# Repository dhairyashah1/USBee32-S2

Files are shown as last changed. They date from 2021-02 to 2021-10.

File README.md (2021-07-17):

# USBee32-S2 : ESP32-S2 Hardware Design

<p align="center">





  </br>
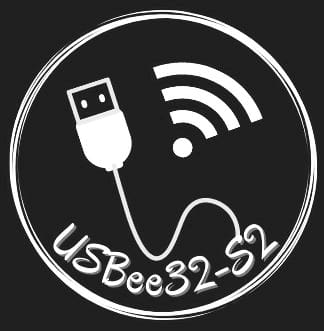
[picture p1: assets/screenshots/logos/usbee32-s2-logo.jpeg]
</p>
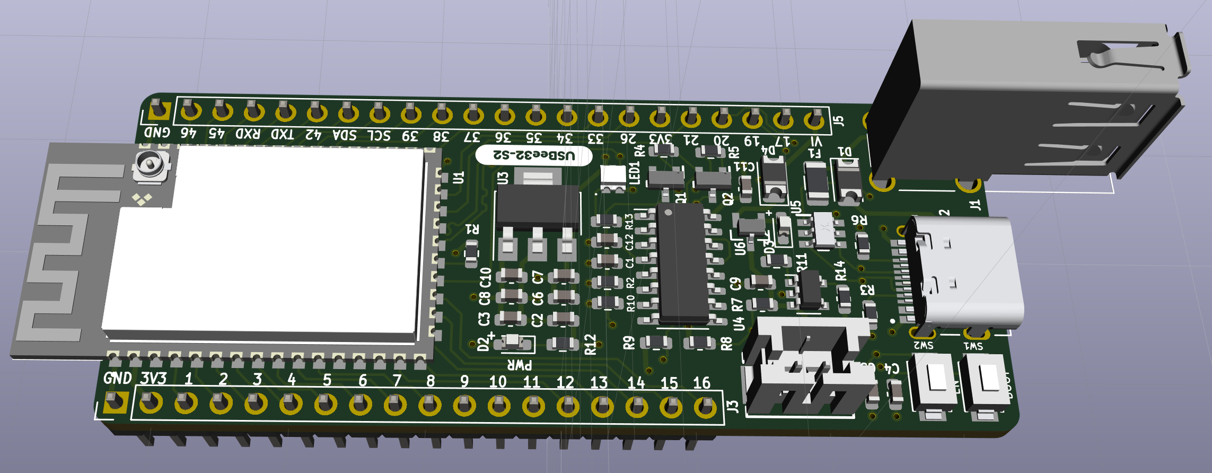
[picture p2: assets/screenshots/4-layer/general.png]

</br>
This repository contains hardware design files and datasheets for the ESP32-S2. This is an open source ESP32-S2 based PCB with breakout ports for both USB - Type A and USB - Type C.
</br>

## Features

* Small form factor of 68.4mm x 27.9mm
* Four layered customly designed general purpose Development board
* Uses ESP32-S2-WROOM RF module
* Breakout ports for both USB - Type A and USB - Type C
* Uses CH340C which gives a high current output converting USB to UART logic
* Powering modes for the ESP - Either can be used
  - USB - A: Using a USB A Male Cable
  - USB - C: Using a USB C Male Cable(Typical Mobile charger cable)
  - VI Pin: Supplying this GPIO pin with external 5V
* Has a On - board debuggable Neopixel (RGB Led)
* Has an ESD protection device which protects the circuit from electrostatic discharge and prevents malfunction/breakdown of the device
* Uses MCP73831 for charging LiPo battery
* Can use it as a power/communicating device for a joystick/ game controller
* Space efficient PCB with integrating majority components in SMD type package 

## Project Structure

```
/assets/datasheets  - contains datasheets of various components used in the PCB
/assets/references  - contains references for the PCB
/assets/schematics  - contains schematics of the the PCB
/assets/screenshots - contains screenshots of the the PCB
.
├── assets
│   ├── datasheets   - contains datasheets of various components used in the PCB         
│   ├── references   - contains references used in making the PCB
│   ├── schematics   - contains schematics of the PCB
│   └── screenshots  - contains screenshots of the PCB
├── gerbers          - contains exportable gerber files of the PCB
├── renders          - contains models and renders of the PCB
└── USBee32-S2       
    ├── component_libraries  - contains external component libraries used 
    └── ...                  - various KiCAD PCB files
```

## Tools

To view/modify the files from this repository, install KiCAD from: [https://kicad.org](https://kicad.org)

## Schematics

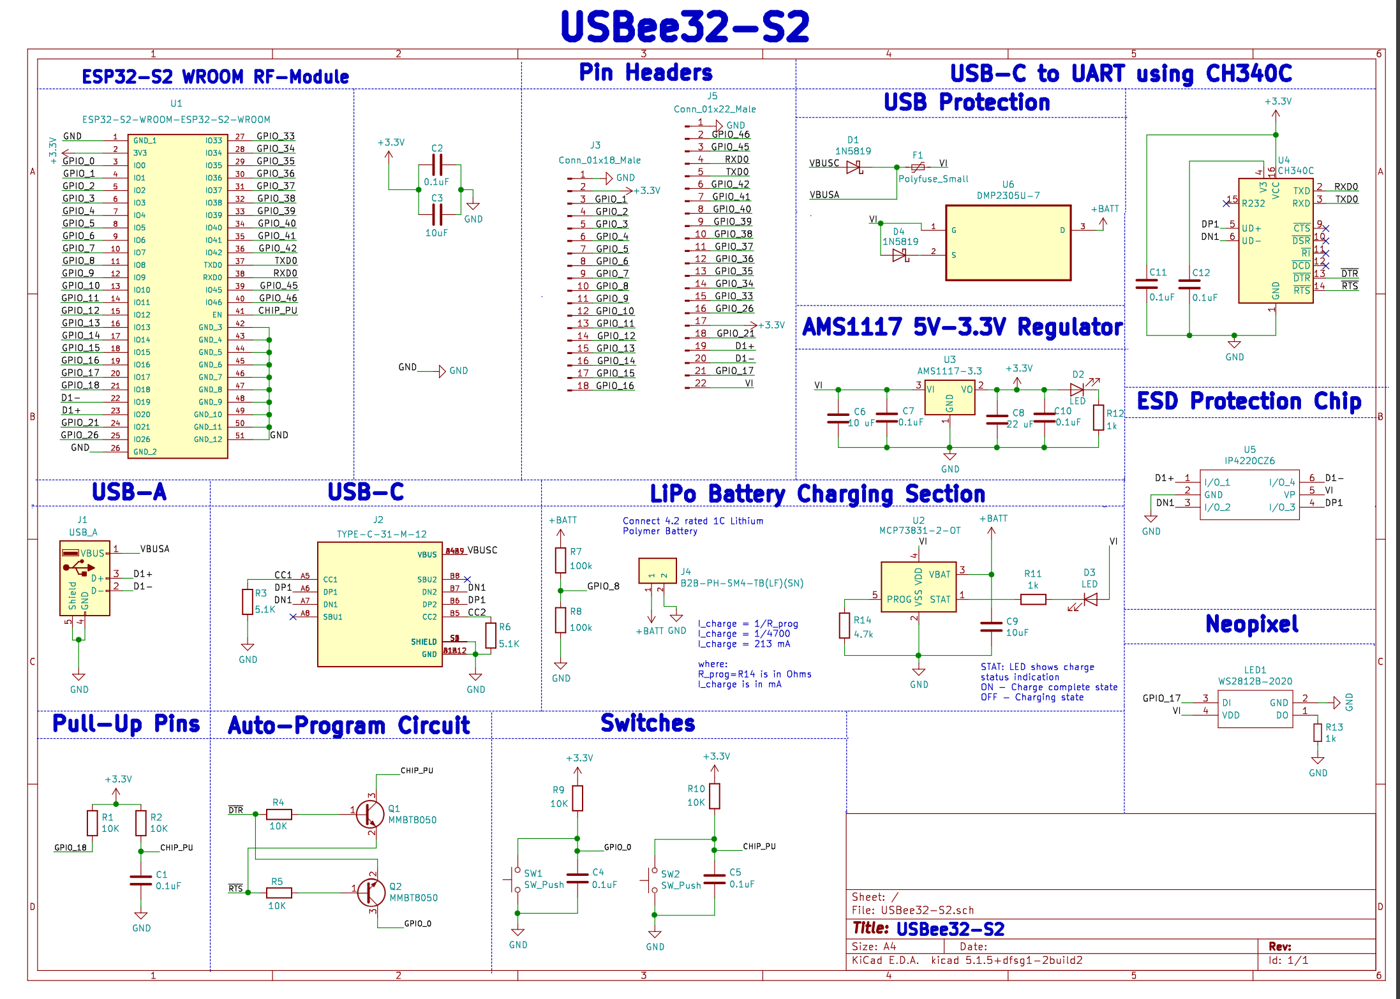
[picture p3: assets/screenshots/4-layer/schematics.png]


## Plots
### Front side

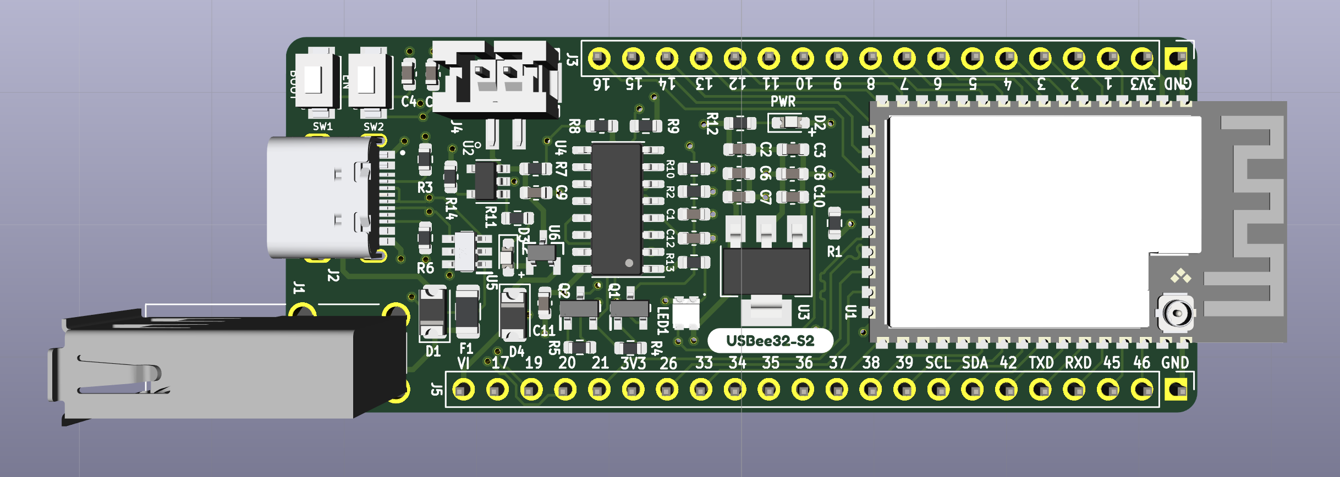
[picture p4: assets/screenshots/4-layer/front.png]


### Back side

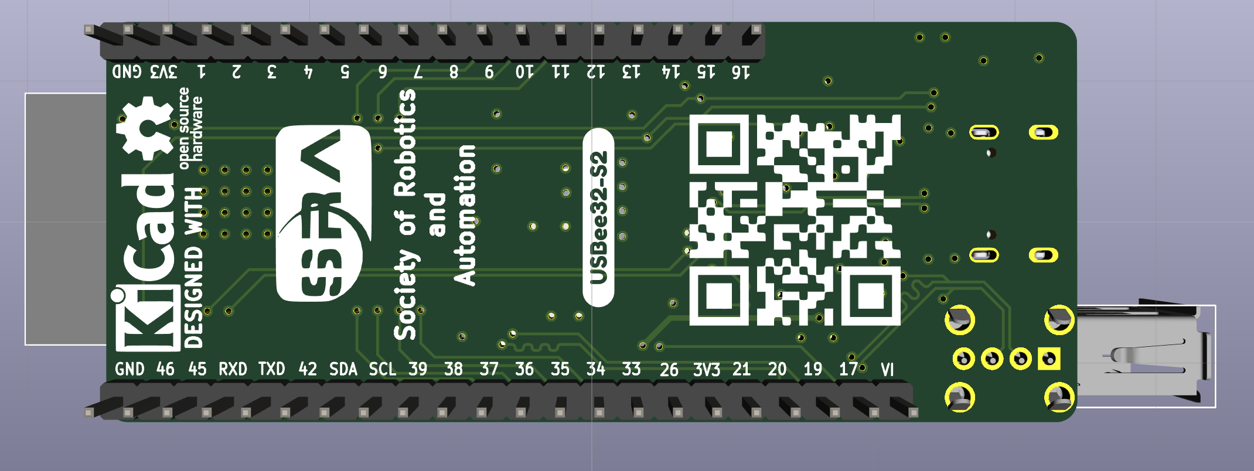
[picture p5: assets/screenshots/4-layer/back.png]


## Future work

- [x] Switching to a 4-layer PCB to make it more space efficient
- [x] Adding safety against electrostatic discharge (ESD)
- [x] Adding Neopixel RBG Leds
- [x] Adding Battery charging circuit
- [x] Adding Safety against ESD - Electrostatic Discharge
- [ ] Adding extra components to the board to deliver better functionality (Eg: OLED)
- [ ] Adding various general purpose sensors 
- [ ] Adding Firmware support

## Documentation
- Click [here](https://dhairyashah1.github.io/USBee32-S2/) to view

## Bill of Materials
- Click [here](https://docs.google.com/spreadsheets/d/1pFtIJ-MqmLt7VhAe4oJemrvx9vsikKc4zFzRtyDyzKU/) to view

<!-- CONTRIBUTORS -->
## Contributors

- [Dhairya Shah](https://github.com/dhairyashah1): *Designer*
- [Chaitravi Chalke](https://github.com/chaitravi-ce): *Designer*
- [Sakshi Chikshe](https://github.com/Sakshi-0311): *Designer*
- [Vedant Paranjape](https://github.com/VedantParanjape): *Mentor*
- [Omkar Bhilare](https://github.com/ombhilare999): *Mentor*

## Sponsorship
- Thanks to PCBWay for sponsoring the first Prototypes.
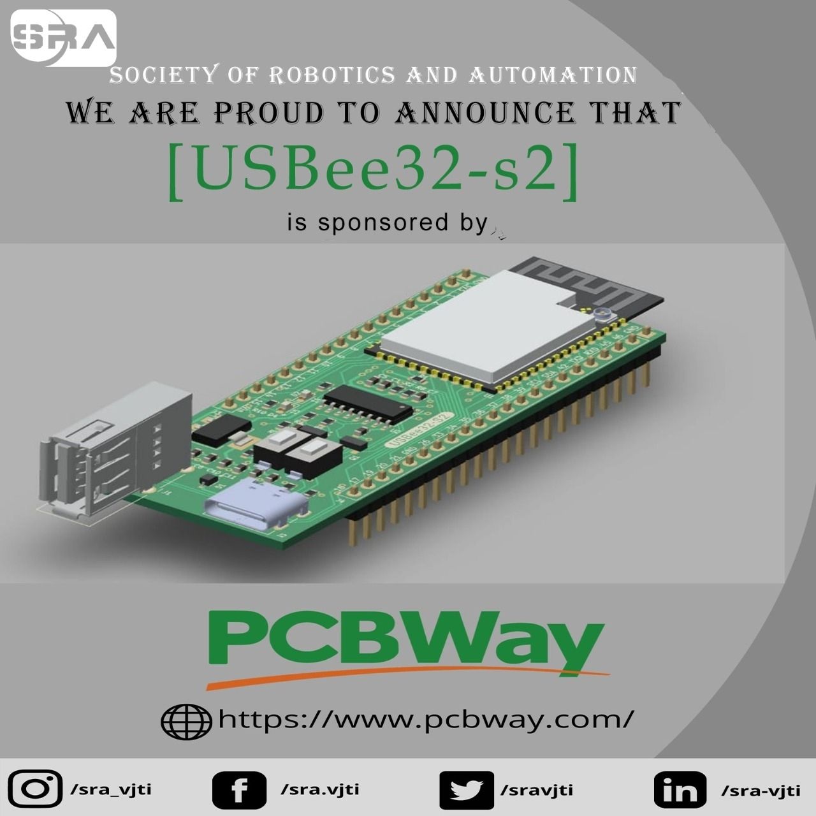
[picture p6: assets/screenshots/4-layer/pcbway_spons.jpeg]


## Organization
- [SRA-VJTI](https://github.com/SRA-VJTI)

## License
- Distributed under the [MIT License](https://github.com/dhairyashah1/pcb-design-ESP32-S2/blob/main/LICENSE).

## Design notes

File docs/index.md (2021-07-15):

# Overview

<p align="center">
    <a href="https://github.com/dhairyashah1/USBee32-S2/tree/4-layerr">
        
    </a>
</p>

<p align="center">





</p>

The USBee32-S2 is an Open Source, General Purpose, USB (Type A and Type C) Breakout Development Board designed using ESP32-S2-WROOM Module. 

The features of USBee32-S2 [printed circuit board](https://github.com/dhairyashah1/USBee32-S2/tree/4-layer) are:   

* Small form factor of 68.4mm x 27.9mm
* Four layered customly designed general purpose Development board
* Uses ESP32-S2-WROOM RF module
* Breakout ports for both USB - Type A and USB - Type C
* Uses CH340C which gives a high current output converting USB to UART logic
* Powering modes for the ESP - Either can be used
  - USB - A: Using a USB A Male Cable
  - USB - C: Using a USB C Male Cable(Typical Mobile charger cable)
  - VI Pin: Supplying this GPIO pin with external 5V
  - JST Battery Port
* Has an On - board debuggable Neopixel (RGB Led)
* Has an ESD protection device which protects the circuit from electrostatic discharge and prevents malfunction/breakdown of the device
* Uses MCP73831 for charging LiPo battery
* Can use it as a power/communicating device for a joystick/ game controller
* Space efficient PCB with integrating majority components in SMD type package 
* Autoselect power source, i.e., battery or USB

## Gallery
<!-- 
## Project logs

* Hackaday: [https://hackaday.io/project/176959-open-authenticator](https://hackaday.io/project/176959-open-authenticator)
## Join the Discussion: -->

<!-- * Discord: [https://discord.gg/kVDdB9kAEP](https://discord.gg/kVDdB9kAEP) -->
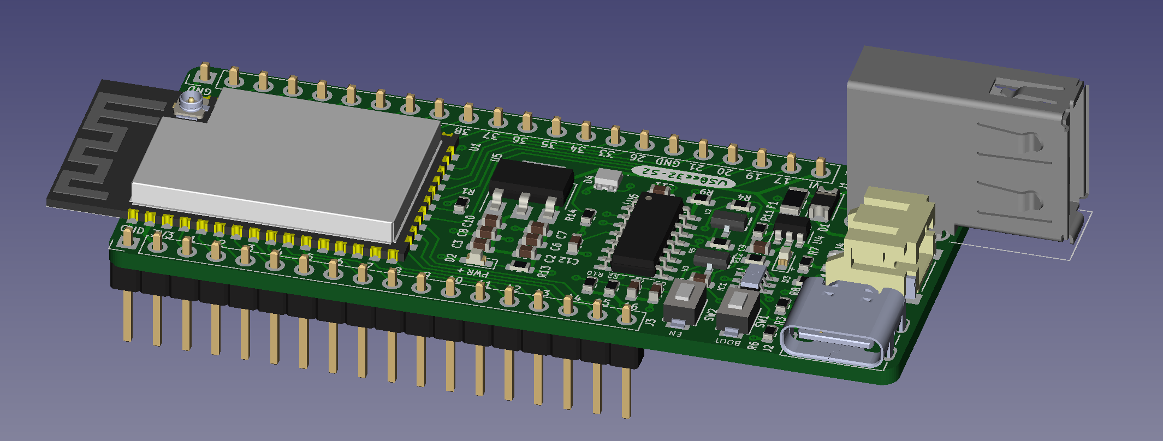
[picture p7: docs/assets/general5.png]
- <h3>General view</h3> 
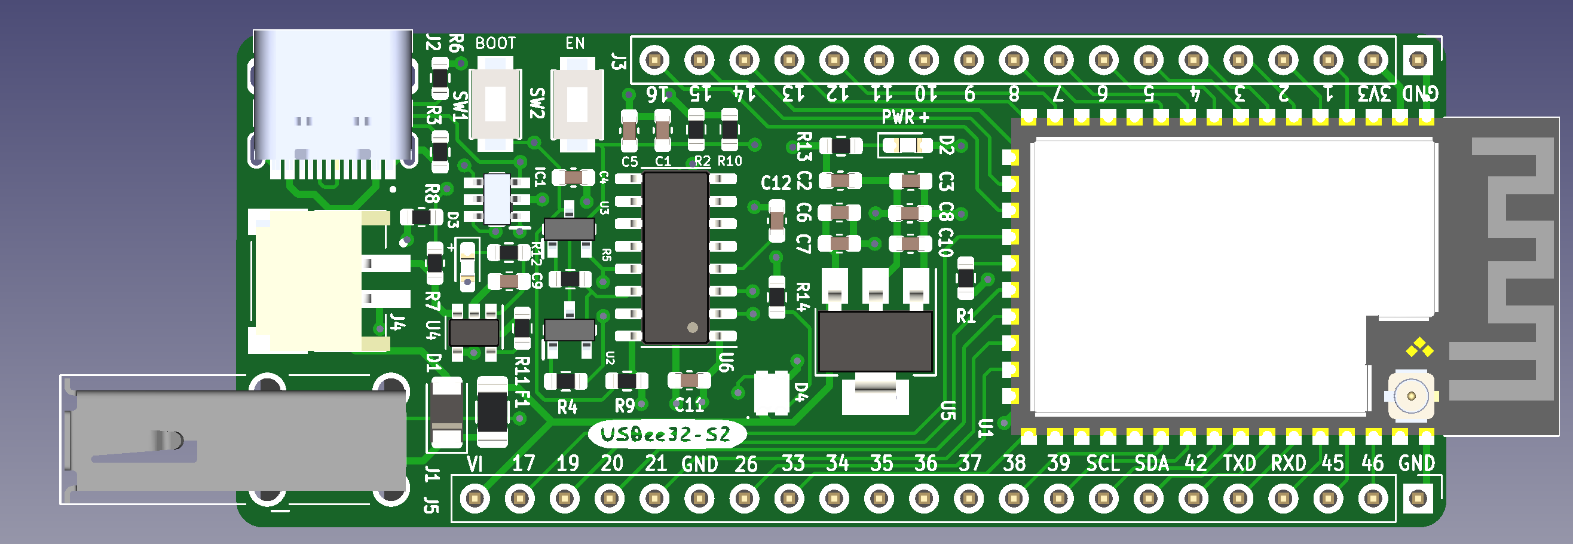
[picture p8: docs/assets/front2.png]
- <h3>Front Side view</h3> 
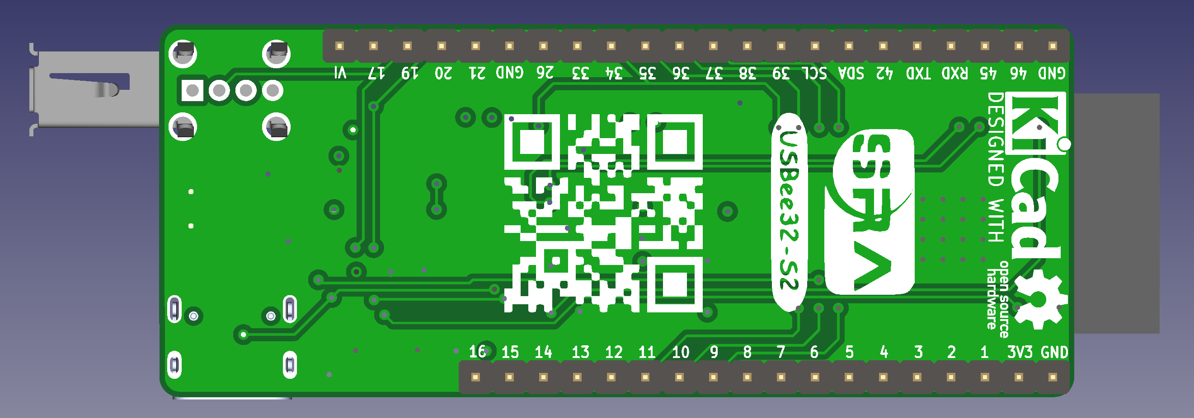
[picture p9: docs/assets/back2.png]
- <h3>Back Side view</h3> 

## Repositories

* PCB Design: [https://github.com/dhairyashah1/USBee32-S2/tree/4-layer](https://github.com/dhairyashah1/USBee32-S2/tree/4-layer)

### Components

* [Bill of Materials](https://docs.google.com/spreadsheets/d/1bL3xiH2Zh8nPkFcn60B3-9qF9RpFs6EWBHacvU51Qi4/edit#gid=0)

## Sponsors

<!-- * [OSHPark](https://oshpark.com/) - Thanks to OSHPark for sponsoring first prototype -->
* [PCBWay](https://www.pcbway.com/) - Thanks to PCBway for sponsoring the first prototype
<!-- * [Asahitec](https://www.asahitec.in/index.html) - Thanks for discounts on stencil -->

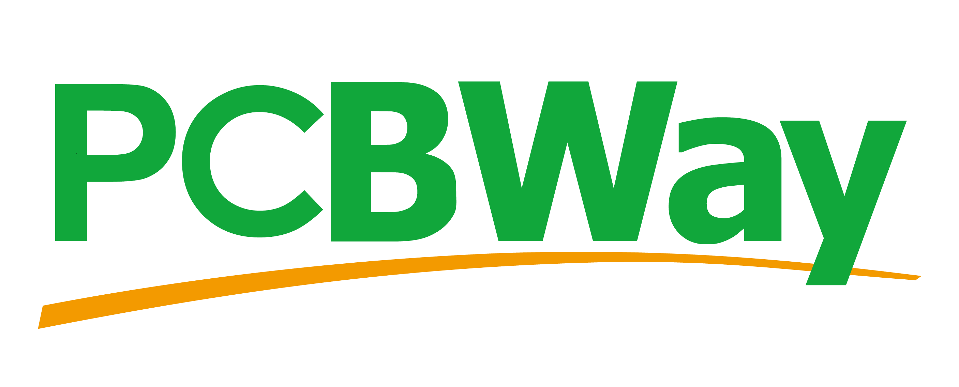
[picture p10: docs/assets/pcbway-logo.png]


<!-- <img src="./assets/oshpark_logo.png" width=128 height=128>
<img src="./assets/asahitec_logo.jpg" width=153 height=94> -->
### Support or Contact

Having trouble with Pages? Check out our [documentation](https://docs.github.com/categories/github-pages-basics/) or [contact support](https://support.github.com/contact) and we’ll help you sort it out.

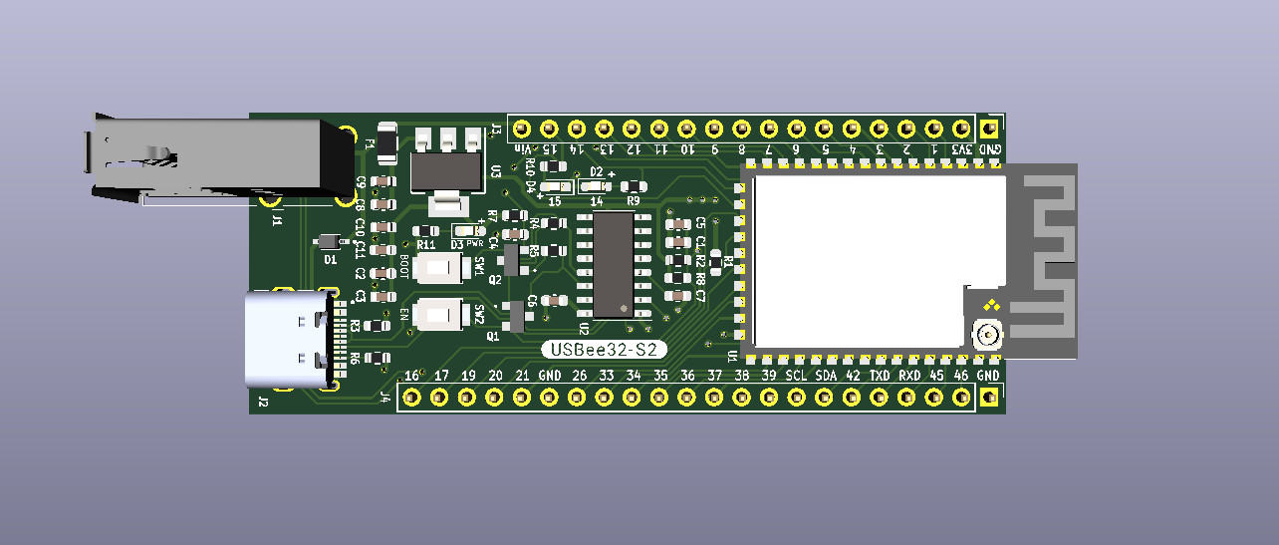
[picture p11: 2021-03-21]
assets/screenshots/2-layer/front.png

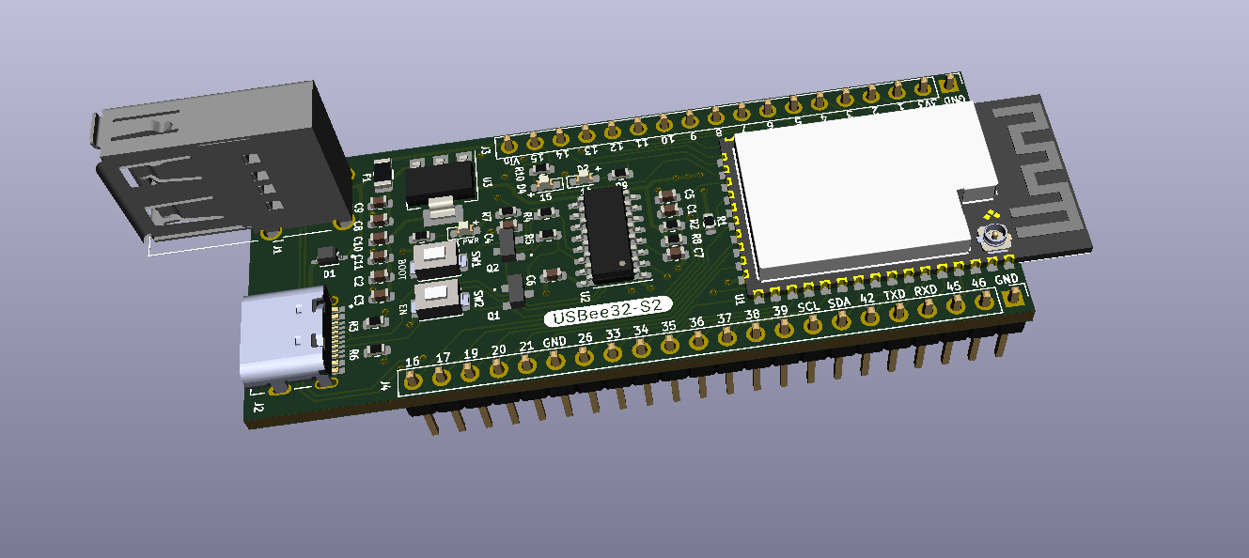
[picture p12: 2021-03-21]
assets/screenshots/2-layer/ESP32-S2.png

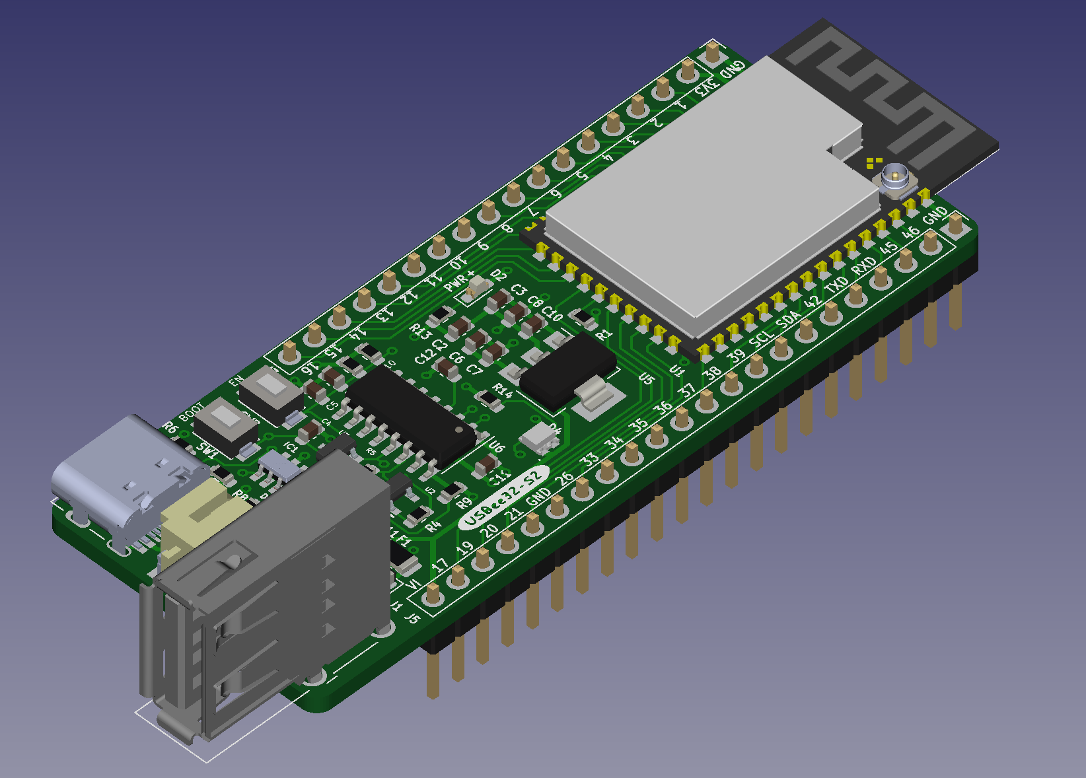
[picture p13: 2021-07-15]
assets/screenshots/4-layer/general6.png

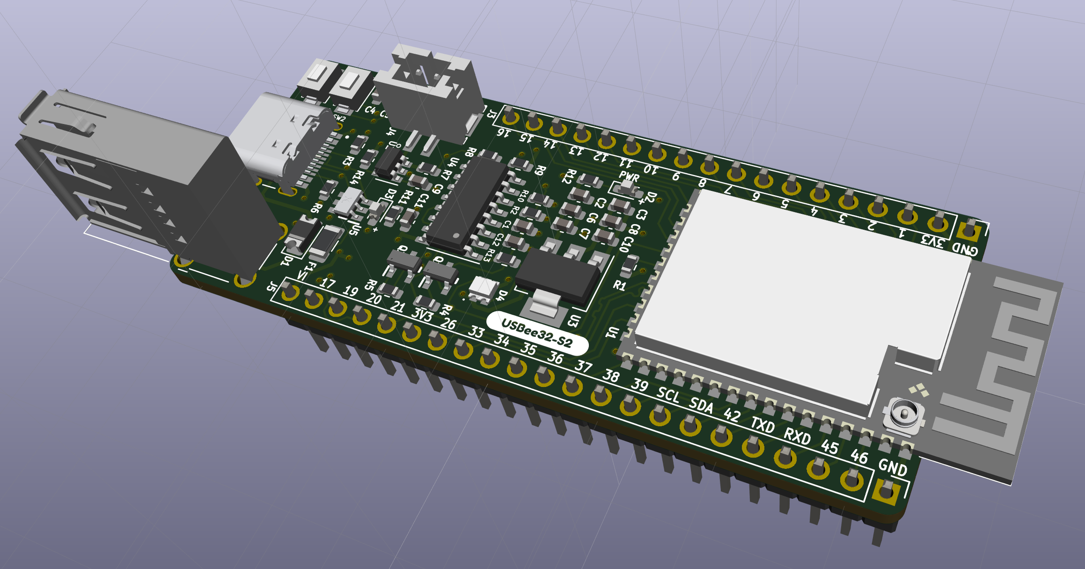
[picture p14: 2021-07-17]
assets/screenshots/4-layer/general3.png

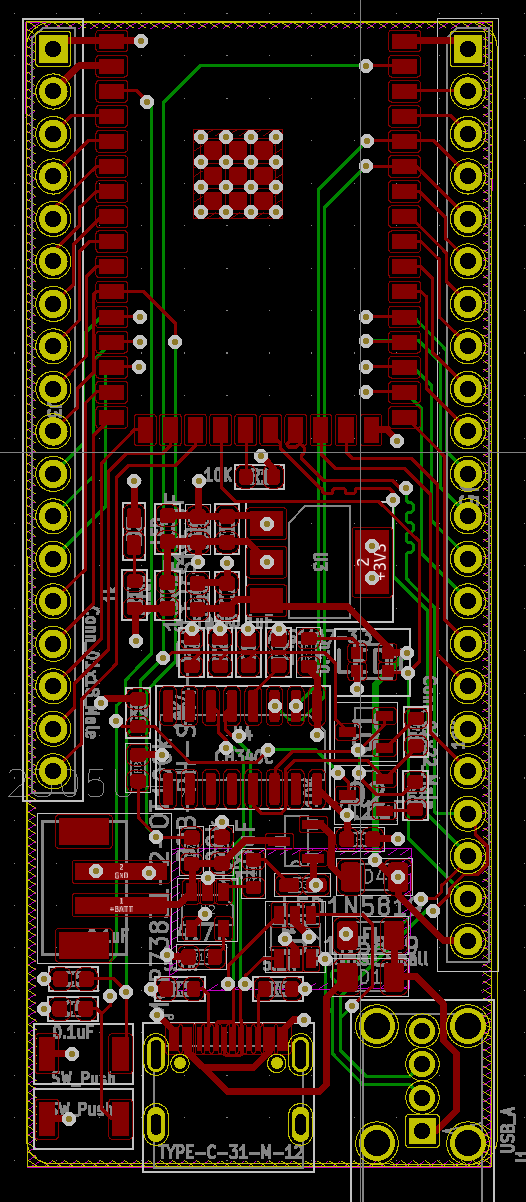
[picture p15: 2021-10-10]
assets/screenshots/4-layer/routing.png

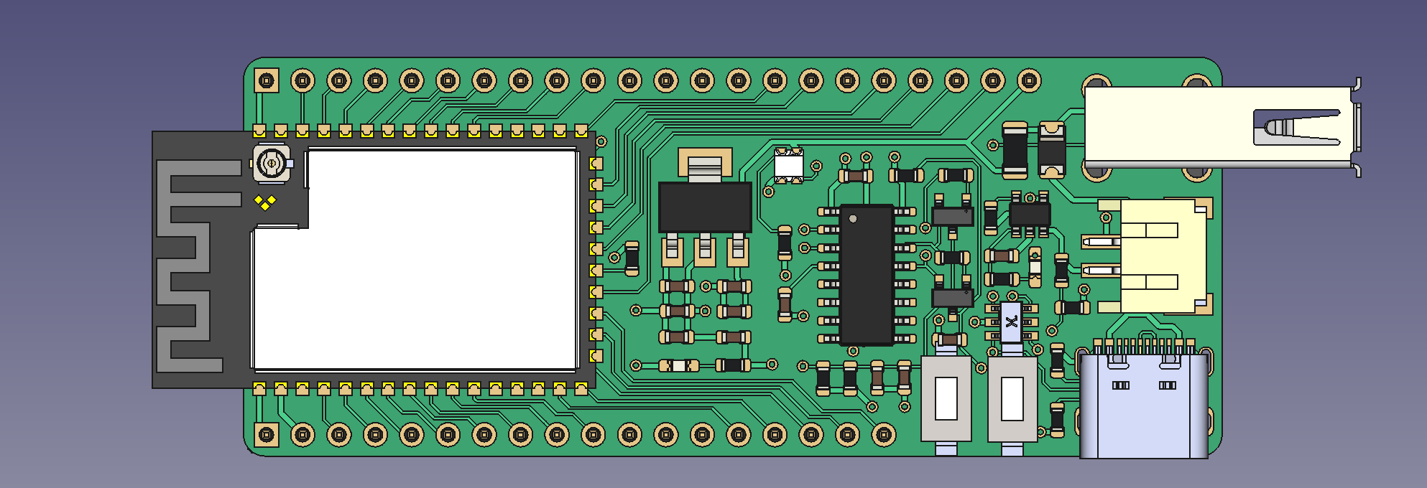
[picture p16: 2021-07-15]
assets/screenshots/4-layer/comic.png

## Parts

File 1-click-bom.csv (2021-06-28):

References | Qty | Description | Manufacturer | MPN | Manufacturer | MPN | Digikey | Mouser | RS | Newark | Farnell
C1 | 1 | C 1uF Unpolarized capacitor 0603 1608Metric
C3 | 1 | C 10uF Unpolarized capacitor 0603 1608Metric
C4, C5, C2, C7, C9, C11, C6 | 7 | C 0.1uF Unpolarized capacitor 0603 1608Metric
C8 | 1 | C 10 uF Unpolarized capacitor 0603 1608Metric
C10 | 1 | C 22 uF Unpolarized capacitor 0603 1608Metric
D1 | 1 | BAT760-7 SOD2513X120N | Diodes Inc. | BAT760-7
D3, D4, D2 | 3 | LED Light emitting diode 0603 1608Metric Castellated
F1 | 1 | Polyfuse Small Resettable fuse, polymeric positive temperature coefficient, small symbol Fuse 1206 3216Metric
J1 | 1 | USB A Type connector Wuerth 614004134726 Horizontal
J2 | 1 | TYPE-C-31-M-12 HRO | HRO Electronics | TYPE-C-31-M-12
J3 | 1 | PinHeader 1x18 P2.54mm Vertical
J4 | 1 | Conn 01x22 Male Generic connector, single row, 01x22, script generated (kicad-library-utils/schlib/autogen/connector/) PinHeader 1x22 P2.54mm Vertical
Q2, Q1 | 2 | Q NPN BCE L8050QLT1G transistor, base/collector/emitter
R6, R3 | 2 | R 5.1K Resistor 0603 1608Metric
R7, R8, R2, R1, R4, R5 | 6 | R 10K Resistor 0603 1608Metric
R11, R9, R10 | 3 | R 1k Resistor 0603 1608Metric
SW1, SW2 | 2 | SW Push button switch, generic, two pins tactile smd switch
U1 | 1 | ESP32-S2-WROOM(M22S2H3200PH3Q0) | Espressif Systems | ESP32-S2-WROOM(M22S2H3200PH3Q0)
U2 | 1 | CH340C USB serial converter, UART, SOIC-16 3.9x9.9mm P1.27mm
U3 | 1 | Low Dropout Regulator, 3.3 Volts, SOT-223-4 | Advanced Monolithic Systems | AMS1117-3.3 | Texas Instruments | REG1117-3.3

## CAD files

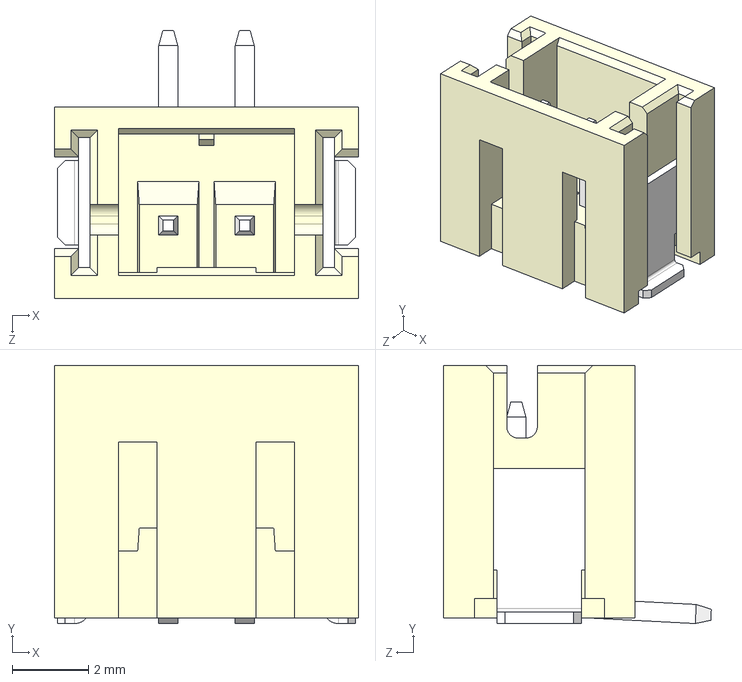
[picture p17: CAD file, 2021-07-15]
USBee32-S2/component_libraries/B2B-PH-SM4-TB/B2B-PH-SM4-TB_LF__SN_.step
7.95 x 6.75 x 7.00 mm

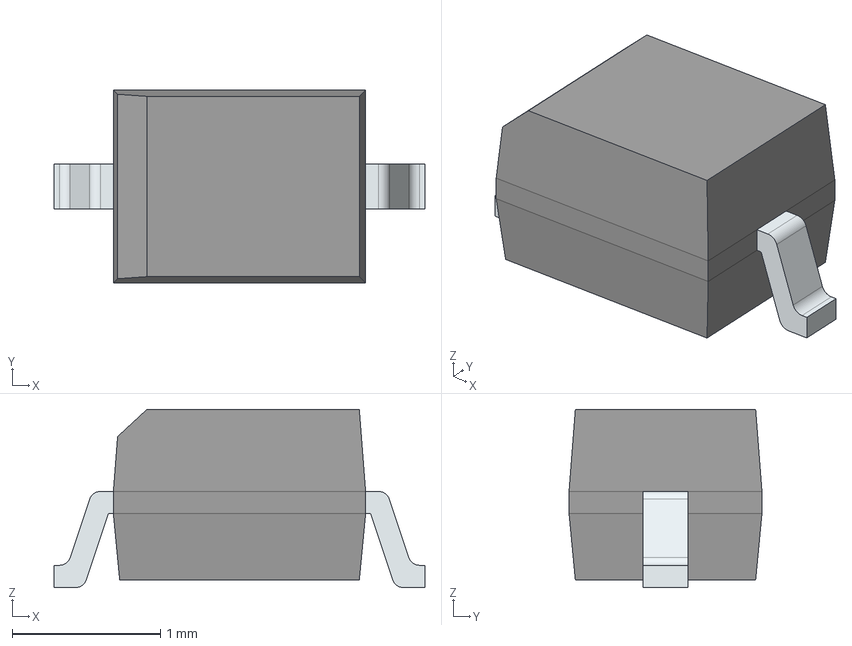
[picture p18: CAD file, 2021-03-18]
USBee32-S2/component_libraries/BAT-760/BAT760-7.stp
2.50 x 1.30 x 1.20 mm
FilletPinL
FilletPinR

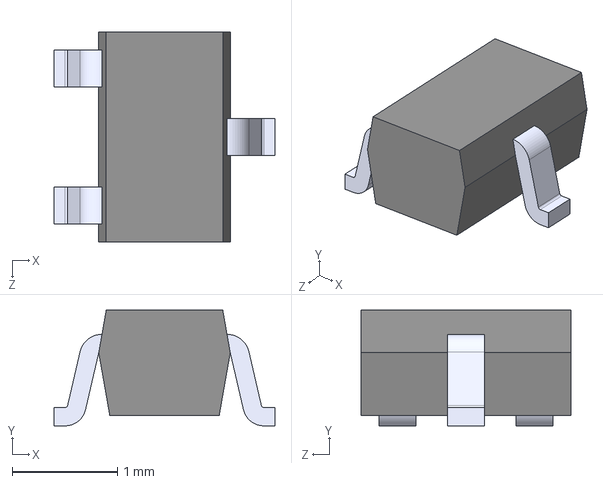
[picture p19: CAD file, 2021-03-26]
USBee32-S2/component_libraries/DMP2305U-7/DMP2305U-7.step
2.10 x 1.10 x 2.00 mm

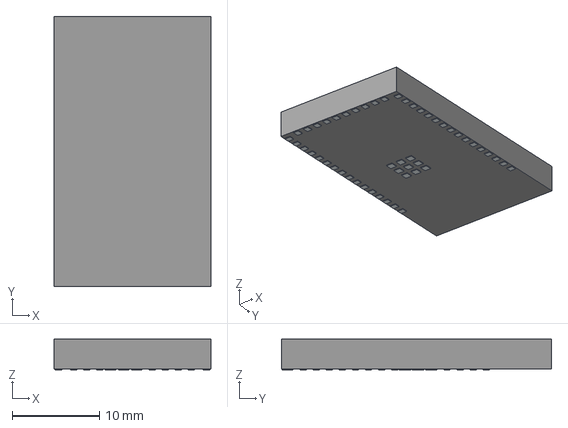
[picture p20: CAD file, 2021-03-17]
USBee32-S2/component_libraries/ESP32-S2-WROOM_M22S2H3200PH3Q0/3D/ESP32-S2-WROOM_M22S2H3200PH3Q0_.stp
18.0 x 31.0 x 3.55 mm
Pins

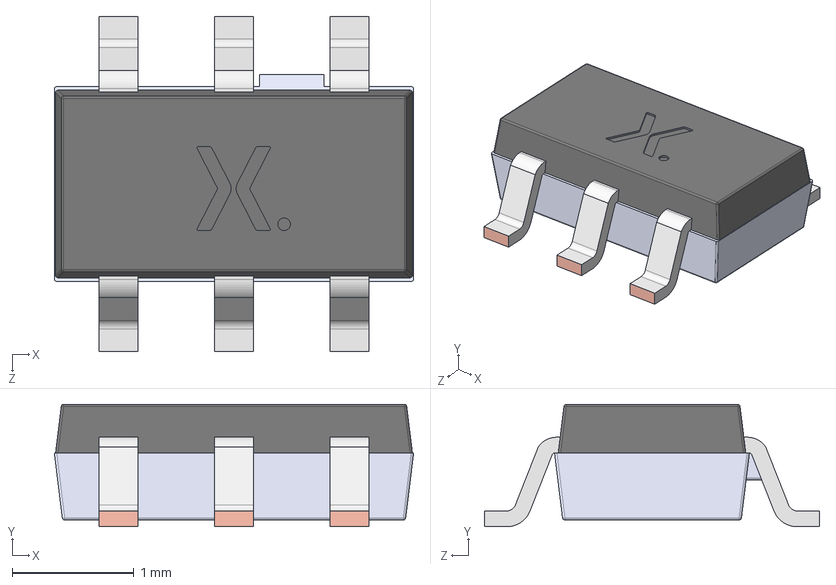
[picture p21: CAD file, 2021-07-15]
USBee32-S2/component_libraries/IP4220CZ6/IP4220CZ6,125.stp
2.95 x 1.01 x 2.75 mm
SOT457 Lower body
SOT457 Lead x 6
SOT457 Upper body

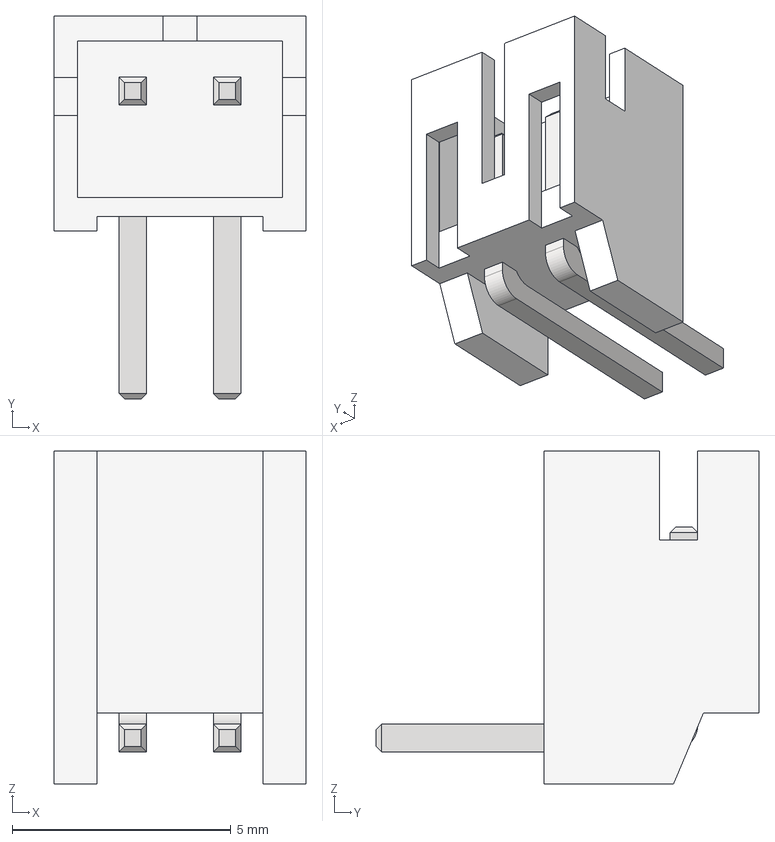
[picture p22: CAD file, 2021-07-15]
USBee32-S2/component_libraries/JST-PH-connector/JST2pinrightangleTHT.stp
5.77 x 8.76 x 7.62 mm

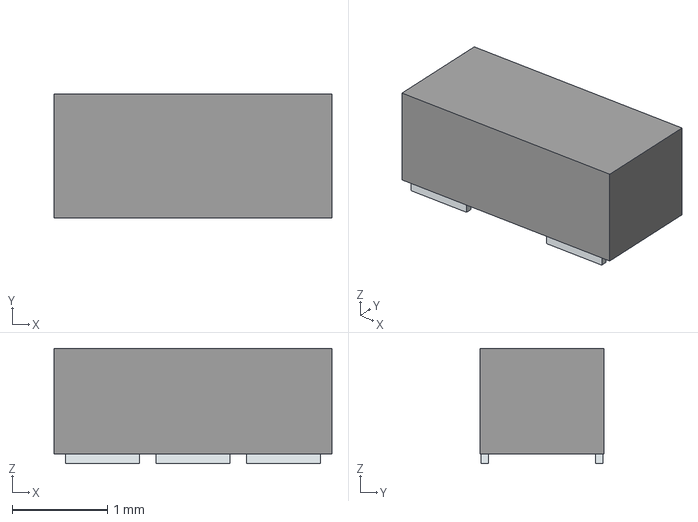
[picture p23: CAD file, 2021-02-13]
USBee32-S2/component_libraries/L8050QLT1G/KiCad/3D/L8050QLT1G.stp
2.92 x 1.30 x 1.21 mm
Pins

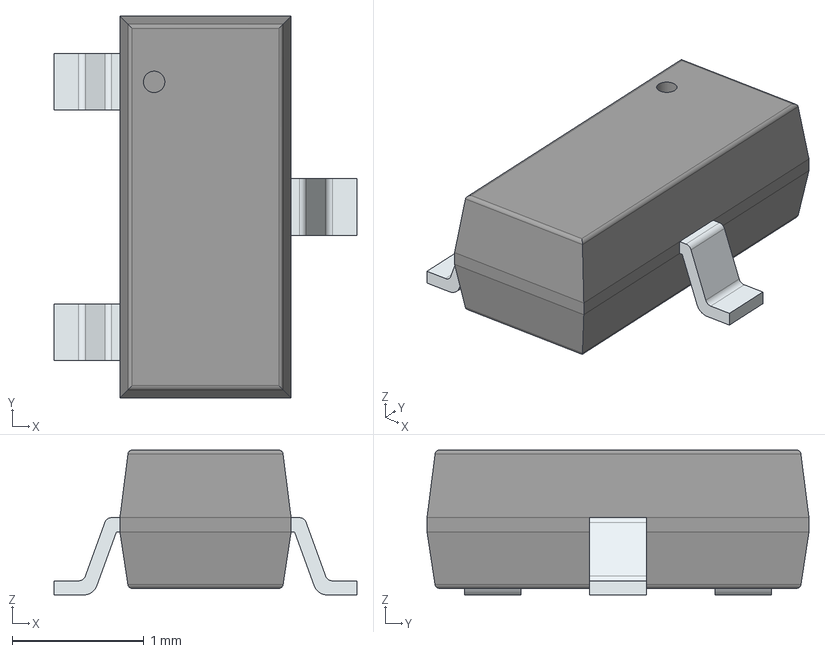
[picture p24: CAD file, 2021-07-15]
USBee32-S2/component_libraries/MMBT8050/MMBT8050.stp
2.30 x 2.90 x 1.10 mm
PinsArrayL
FilletPinR

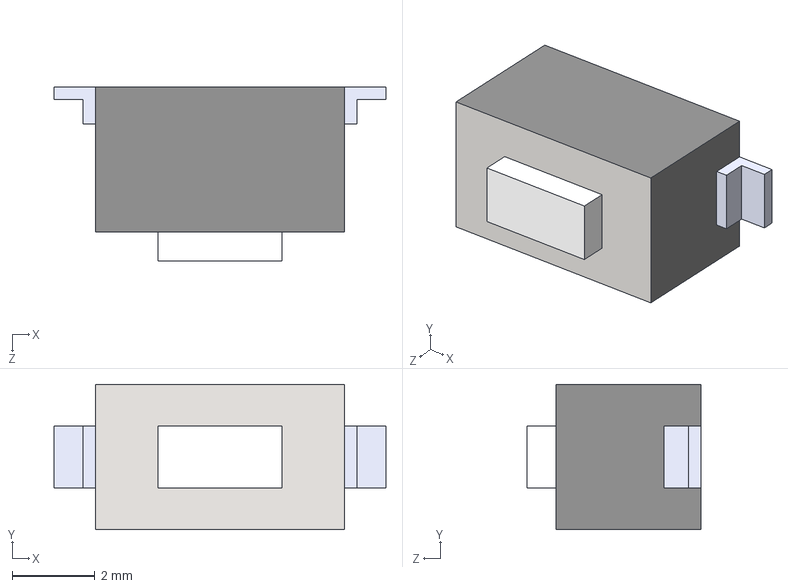
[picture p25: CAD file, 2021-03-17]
USBee32-S2/component_libraries/Tactile-Switch/User Library-KFC-2Pin SMD.STEP
8.00 x 3.50 x 4.20 mm

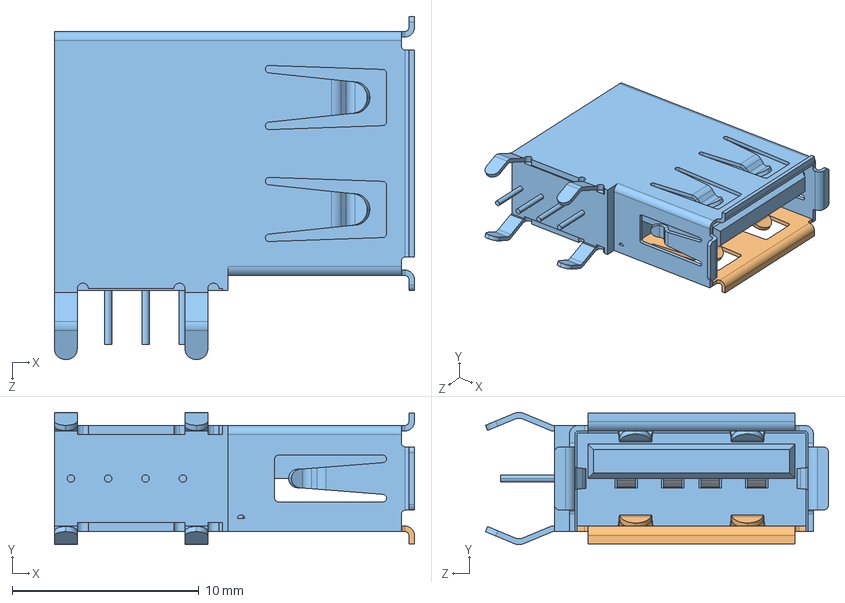
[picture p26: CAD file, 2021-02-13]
USBee32-S2/component_libraries/USB-A-3D/USB-A 111 (vertical on plate).STEP
19.3 x 7.10 x 18.4 mm

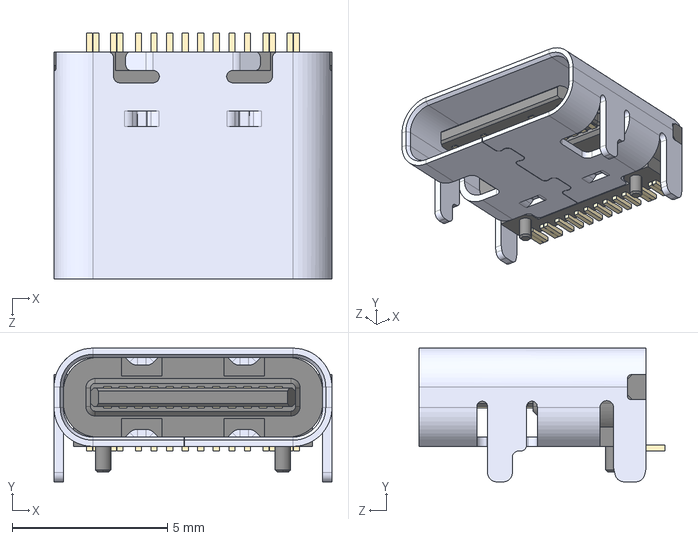
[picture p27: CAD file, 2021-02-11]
USBee32-S2/component_libraries/USB-TYPE-C/TYPE-C-31-M-12.step
8.94 x 4.30 x 7.90 mm

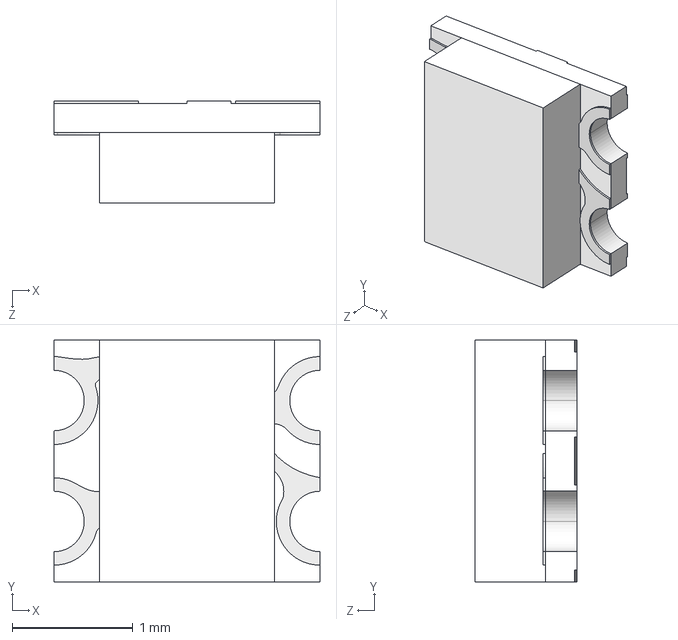
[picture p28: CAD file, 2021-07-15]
USBee32-S2/component_libraries/WS2812B-2020/WS2812-2020.step
2.20 x 2.00 x 0.84 mm

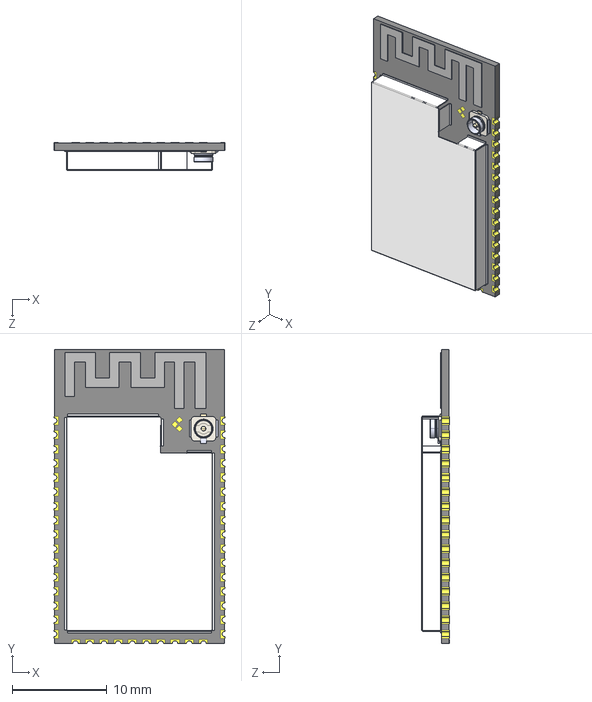
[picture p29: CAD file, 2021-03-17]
USBee32-S2/component_libraries/ESP32-S2-WROOM_M22S2H3200PH3Q0/3D/ESP32-S2-WROVER.STEP
18.0 x 31.0 x 2.91 mm

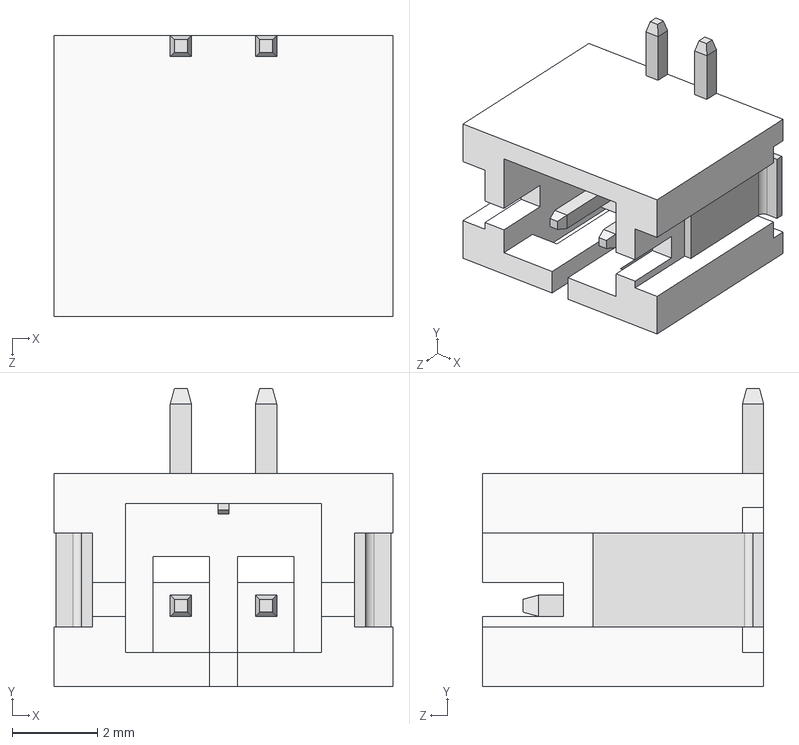
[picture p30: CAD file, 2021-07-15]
USBee32-S2/component_libraries/JST-PH-connector/JST-PH-Rotated-SMD.step
7.95 x 7.00 x 6.60 mm

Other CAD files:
renders/v.1/usbee32-s2.FCStd
renders/v.2/usbee32-s2-realistic.FCStd
renders/v.2/usbee32-s2.FCStd
USBee32-S2/component_libraries/BAT-760/BAT760-7.stl
USBee32-S2/component_libraries/ESP32-S2-WROOM_M22S2H3200PH3Q0/3D/ESP32-S2-WROOM_M22S2H3200PH3Q0_.stl
USBee32-S2/component_libraries/L8050QLT1G/KiCad/3D/L8050QLT1G.stl
USBee32-S2/component_libraries/MMBT8050/MMBT8050.stl
USBee32-S2/component_libraries/USB-A-3D/USB-A 111 (vertical on plate).SLDPRT
gerbers/v.1/ESP32-S2-B_SilkS.dxf
gerbers/v.1/ESP32-S2-F_SilkS.dxf

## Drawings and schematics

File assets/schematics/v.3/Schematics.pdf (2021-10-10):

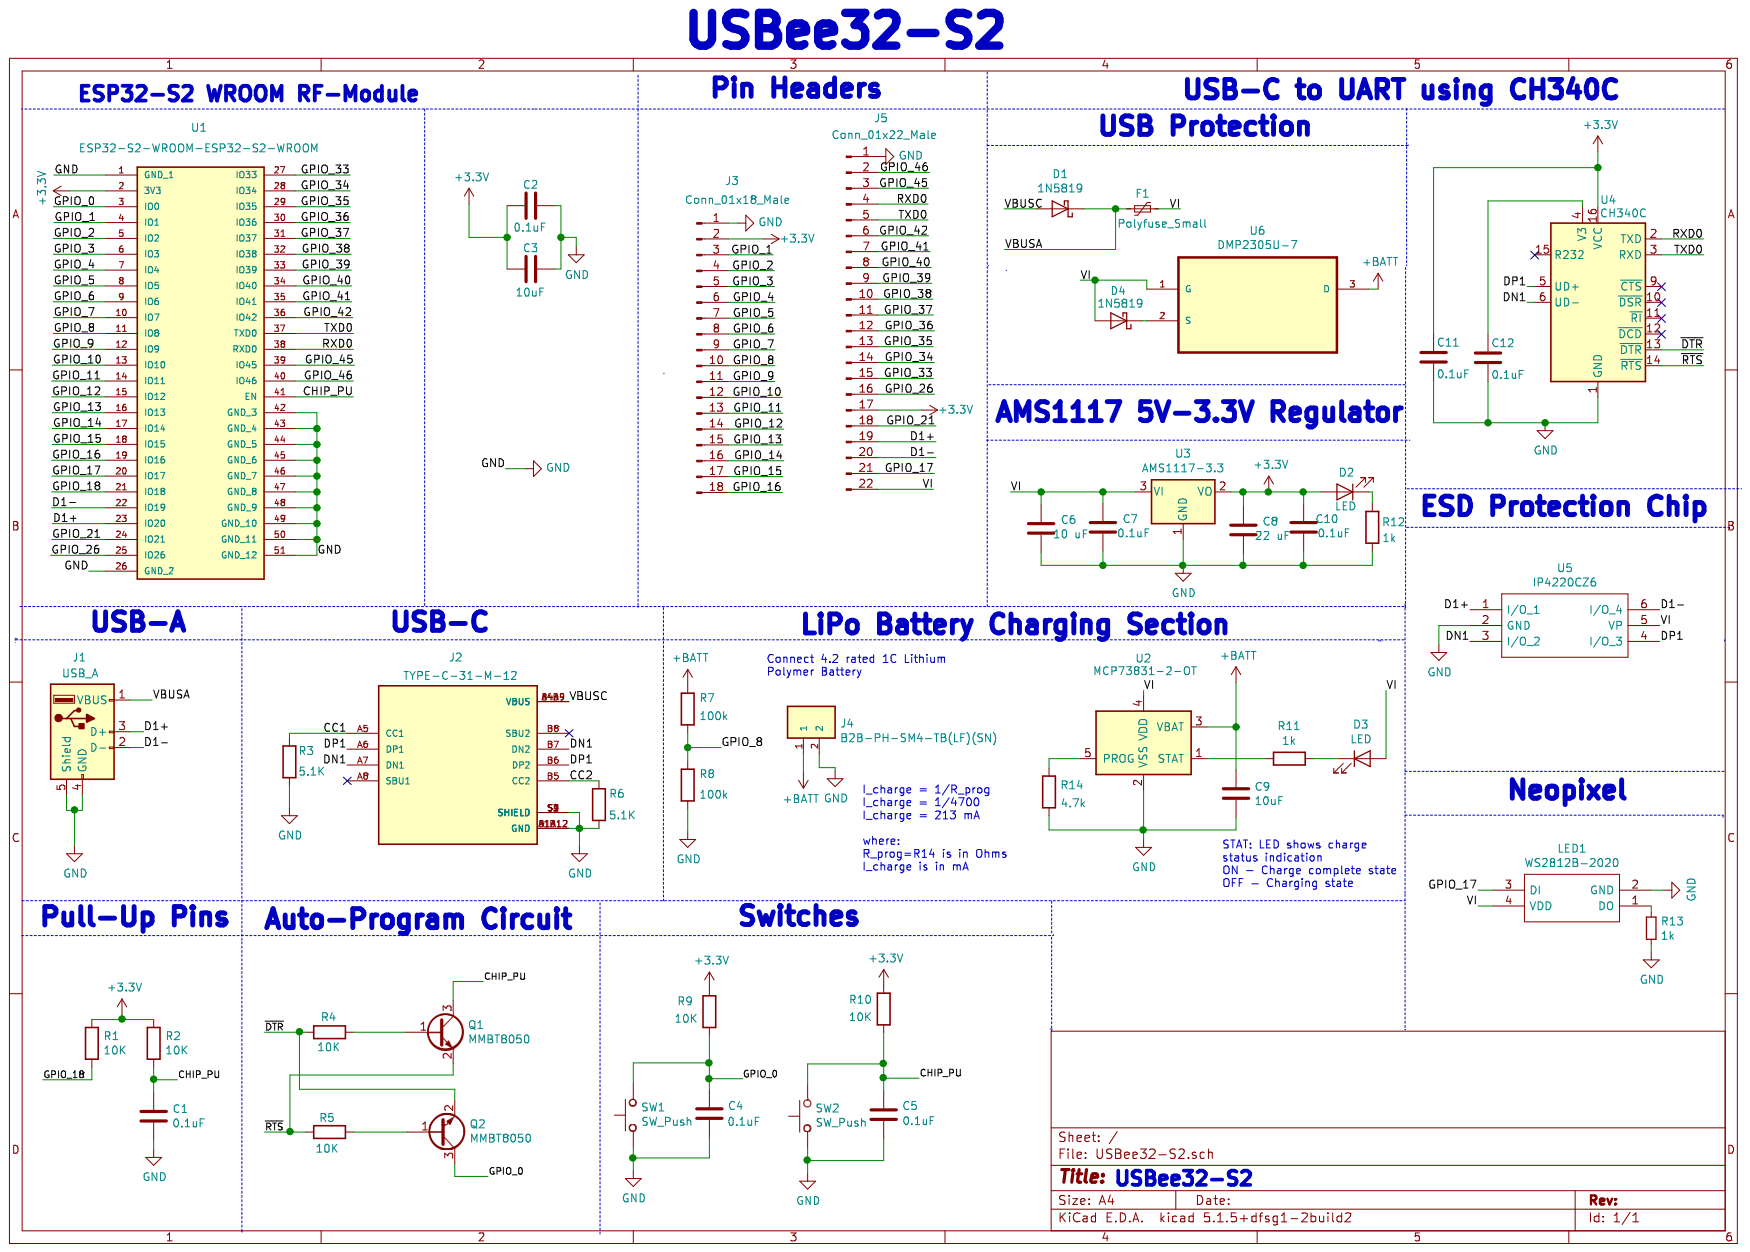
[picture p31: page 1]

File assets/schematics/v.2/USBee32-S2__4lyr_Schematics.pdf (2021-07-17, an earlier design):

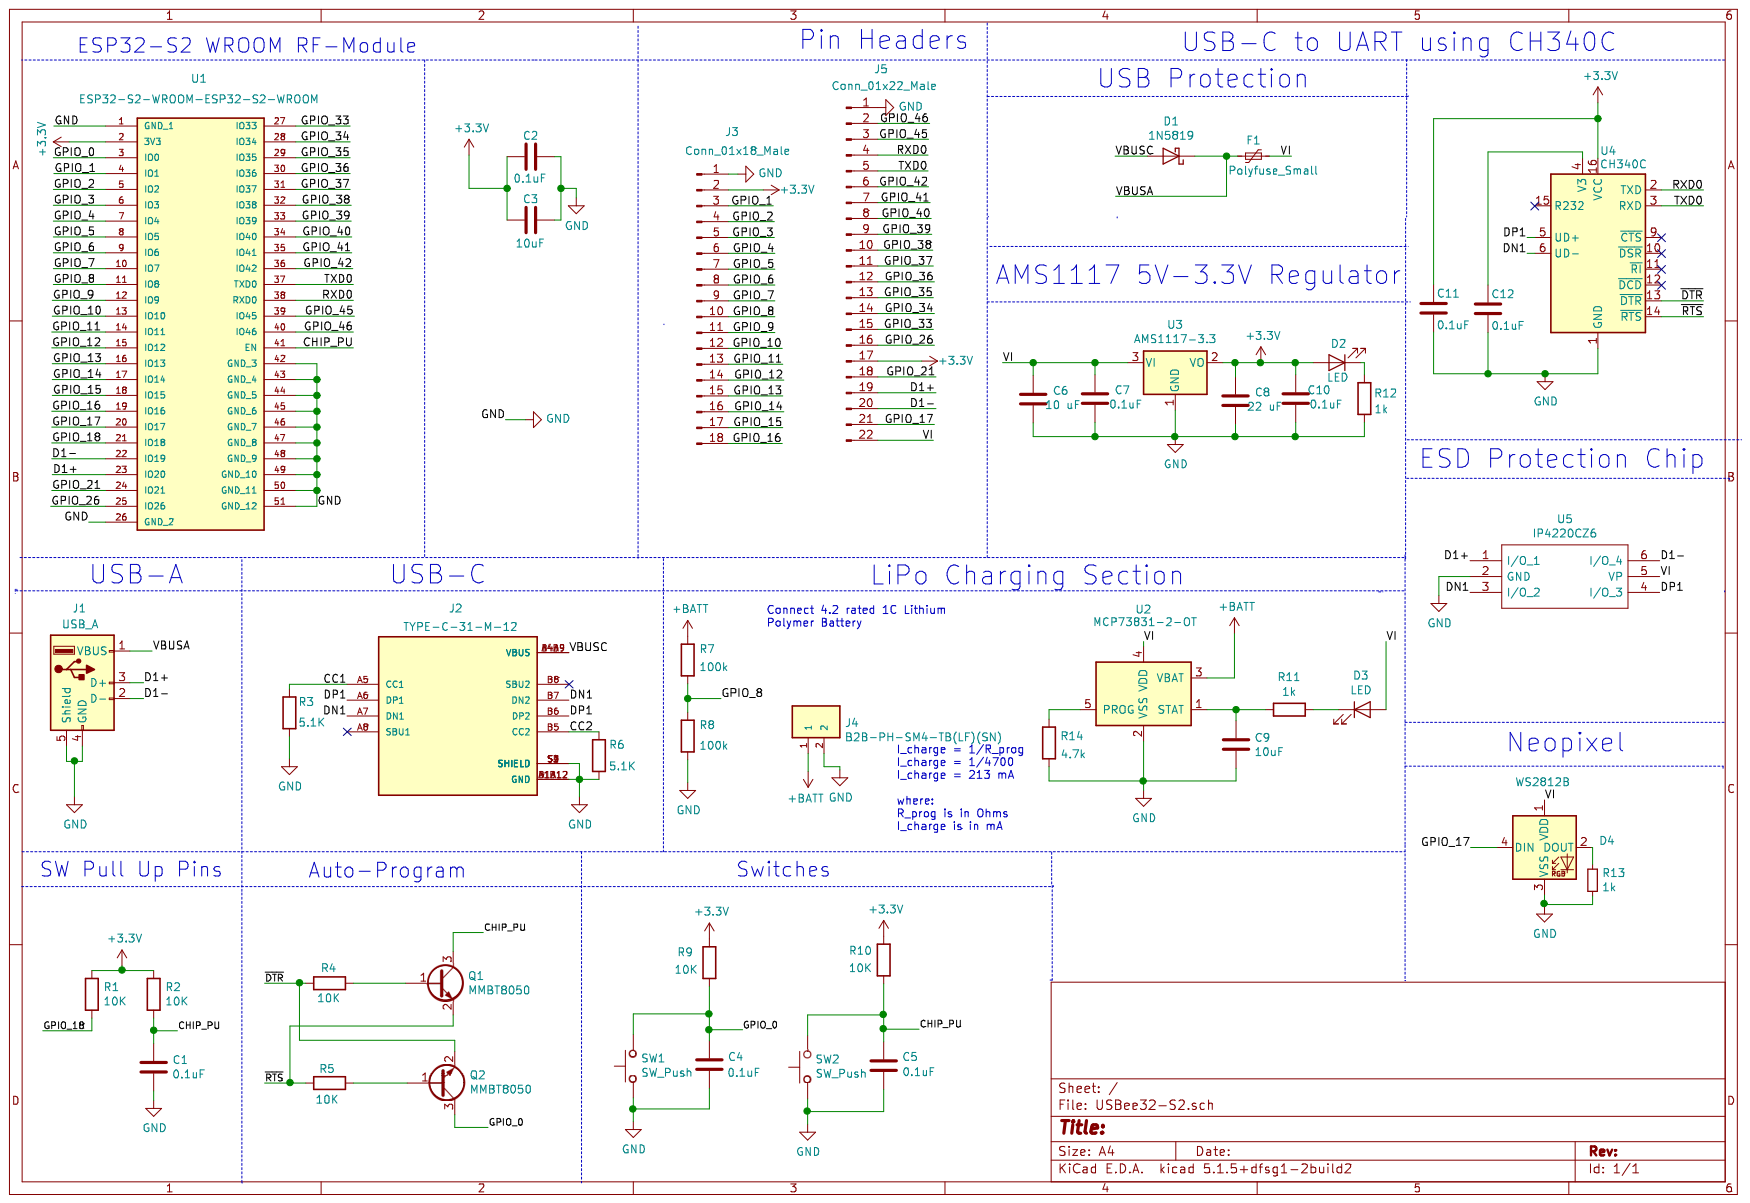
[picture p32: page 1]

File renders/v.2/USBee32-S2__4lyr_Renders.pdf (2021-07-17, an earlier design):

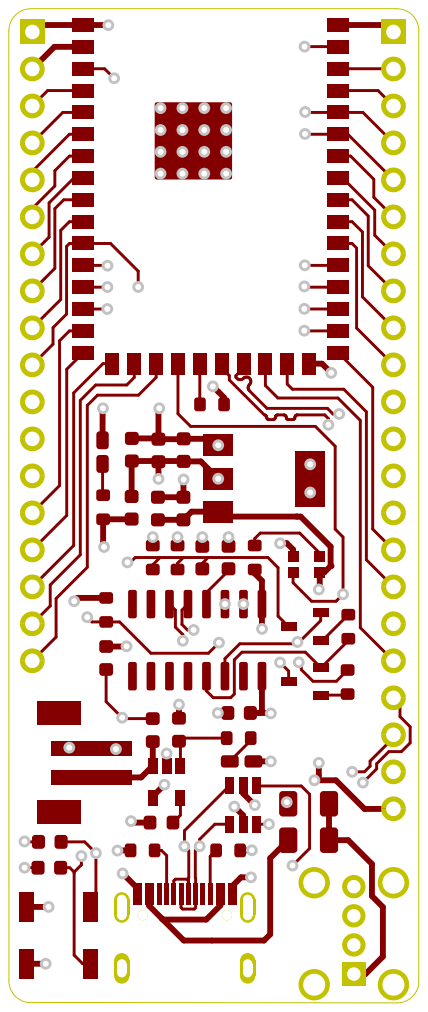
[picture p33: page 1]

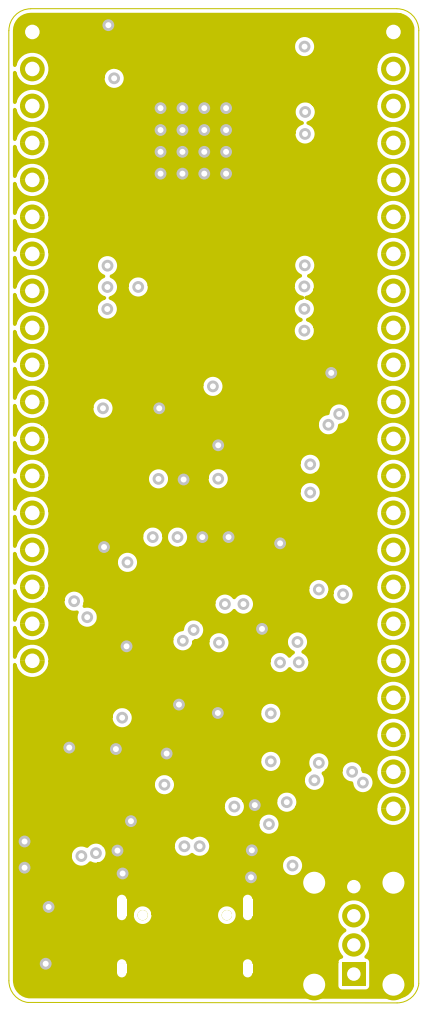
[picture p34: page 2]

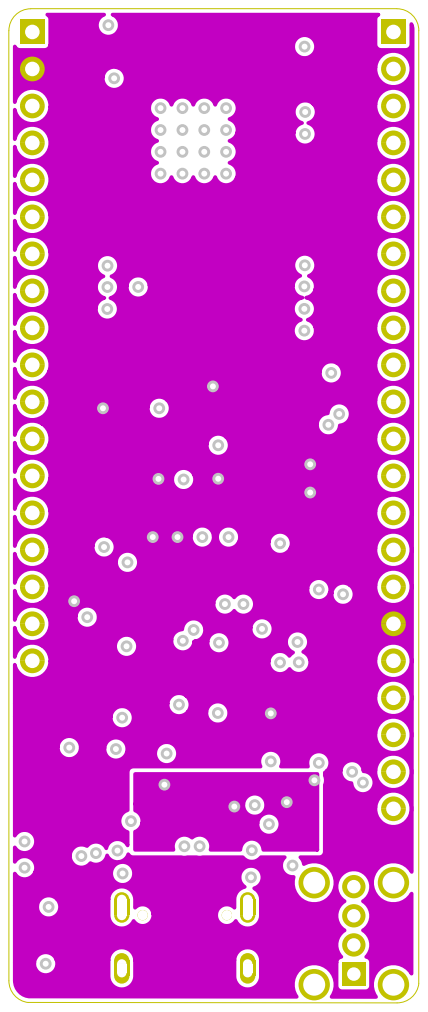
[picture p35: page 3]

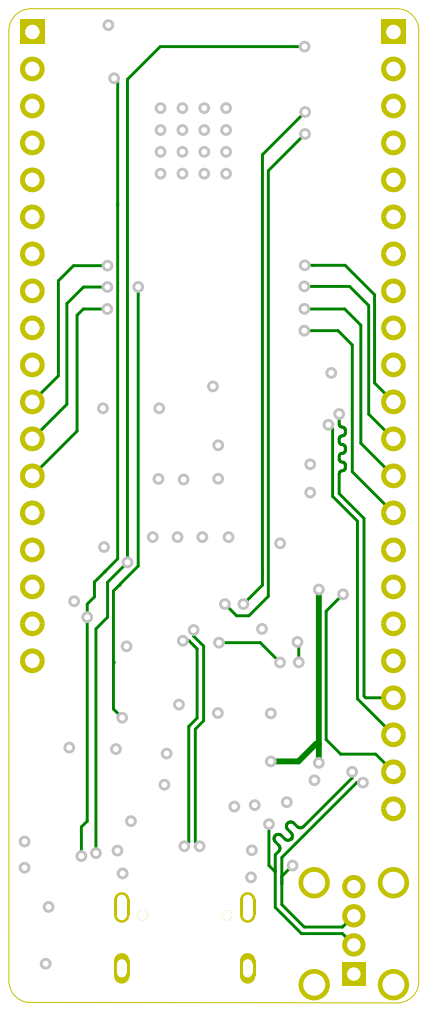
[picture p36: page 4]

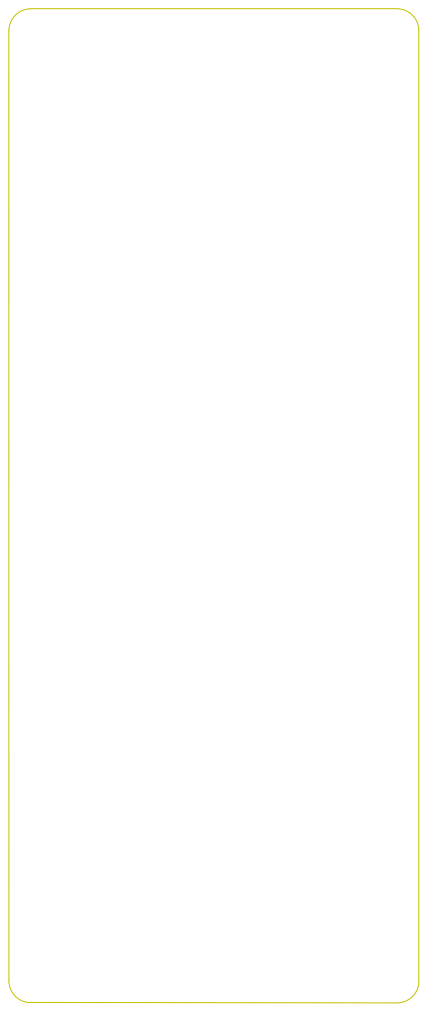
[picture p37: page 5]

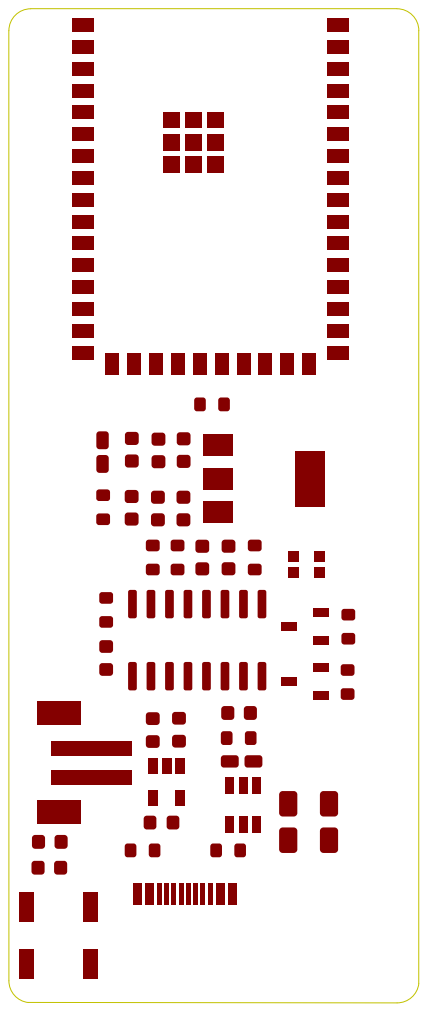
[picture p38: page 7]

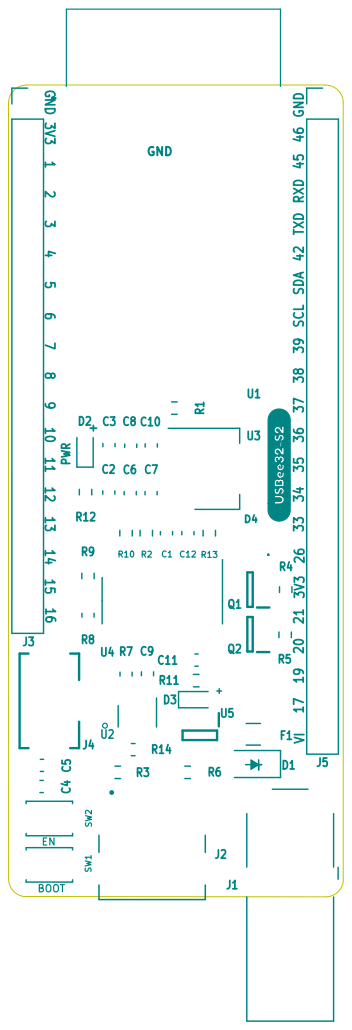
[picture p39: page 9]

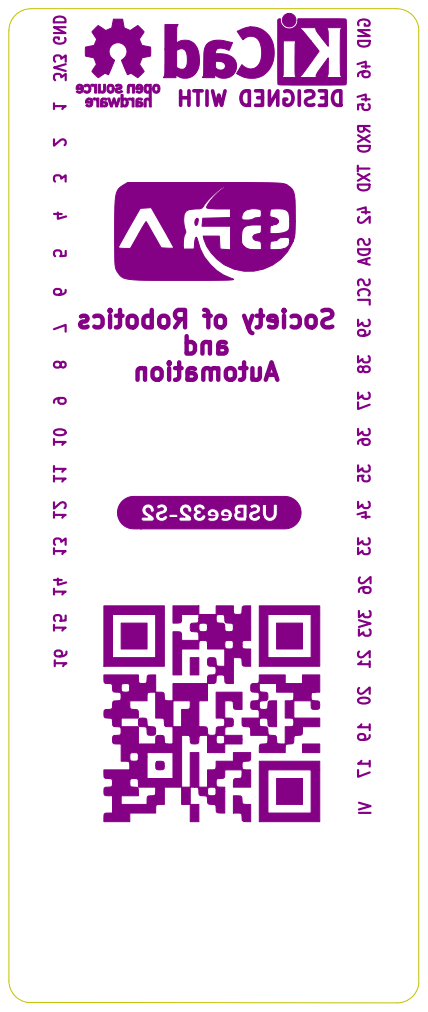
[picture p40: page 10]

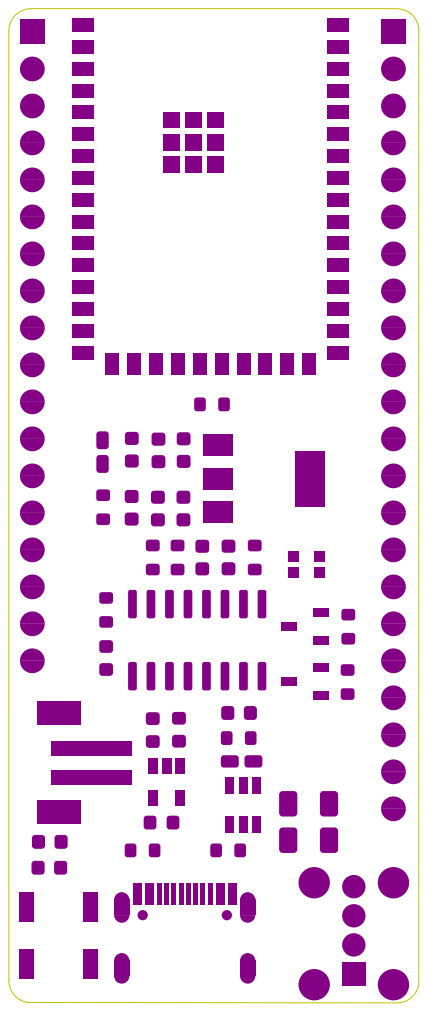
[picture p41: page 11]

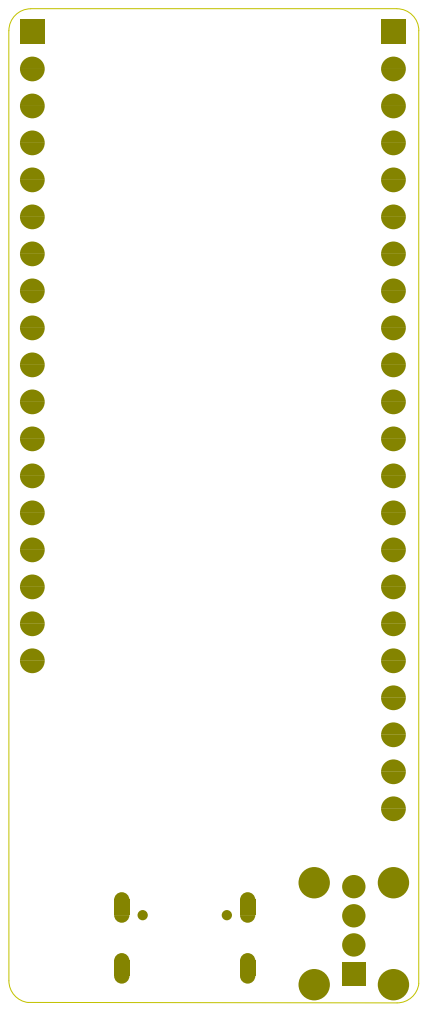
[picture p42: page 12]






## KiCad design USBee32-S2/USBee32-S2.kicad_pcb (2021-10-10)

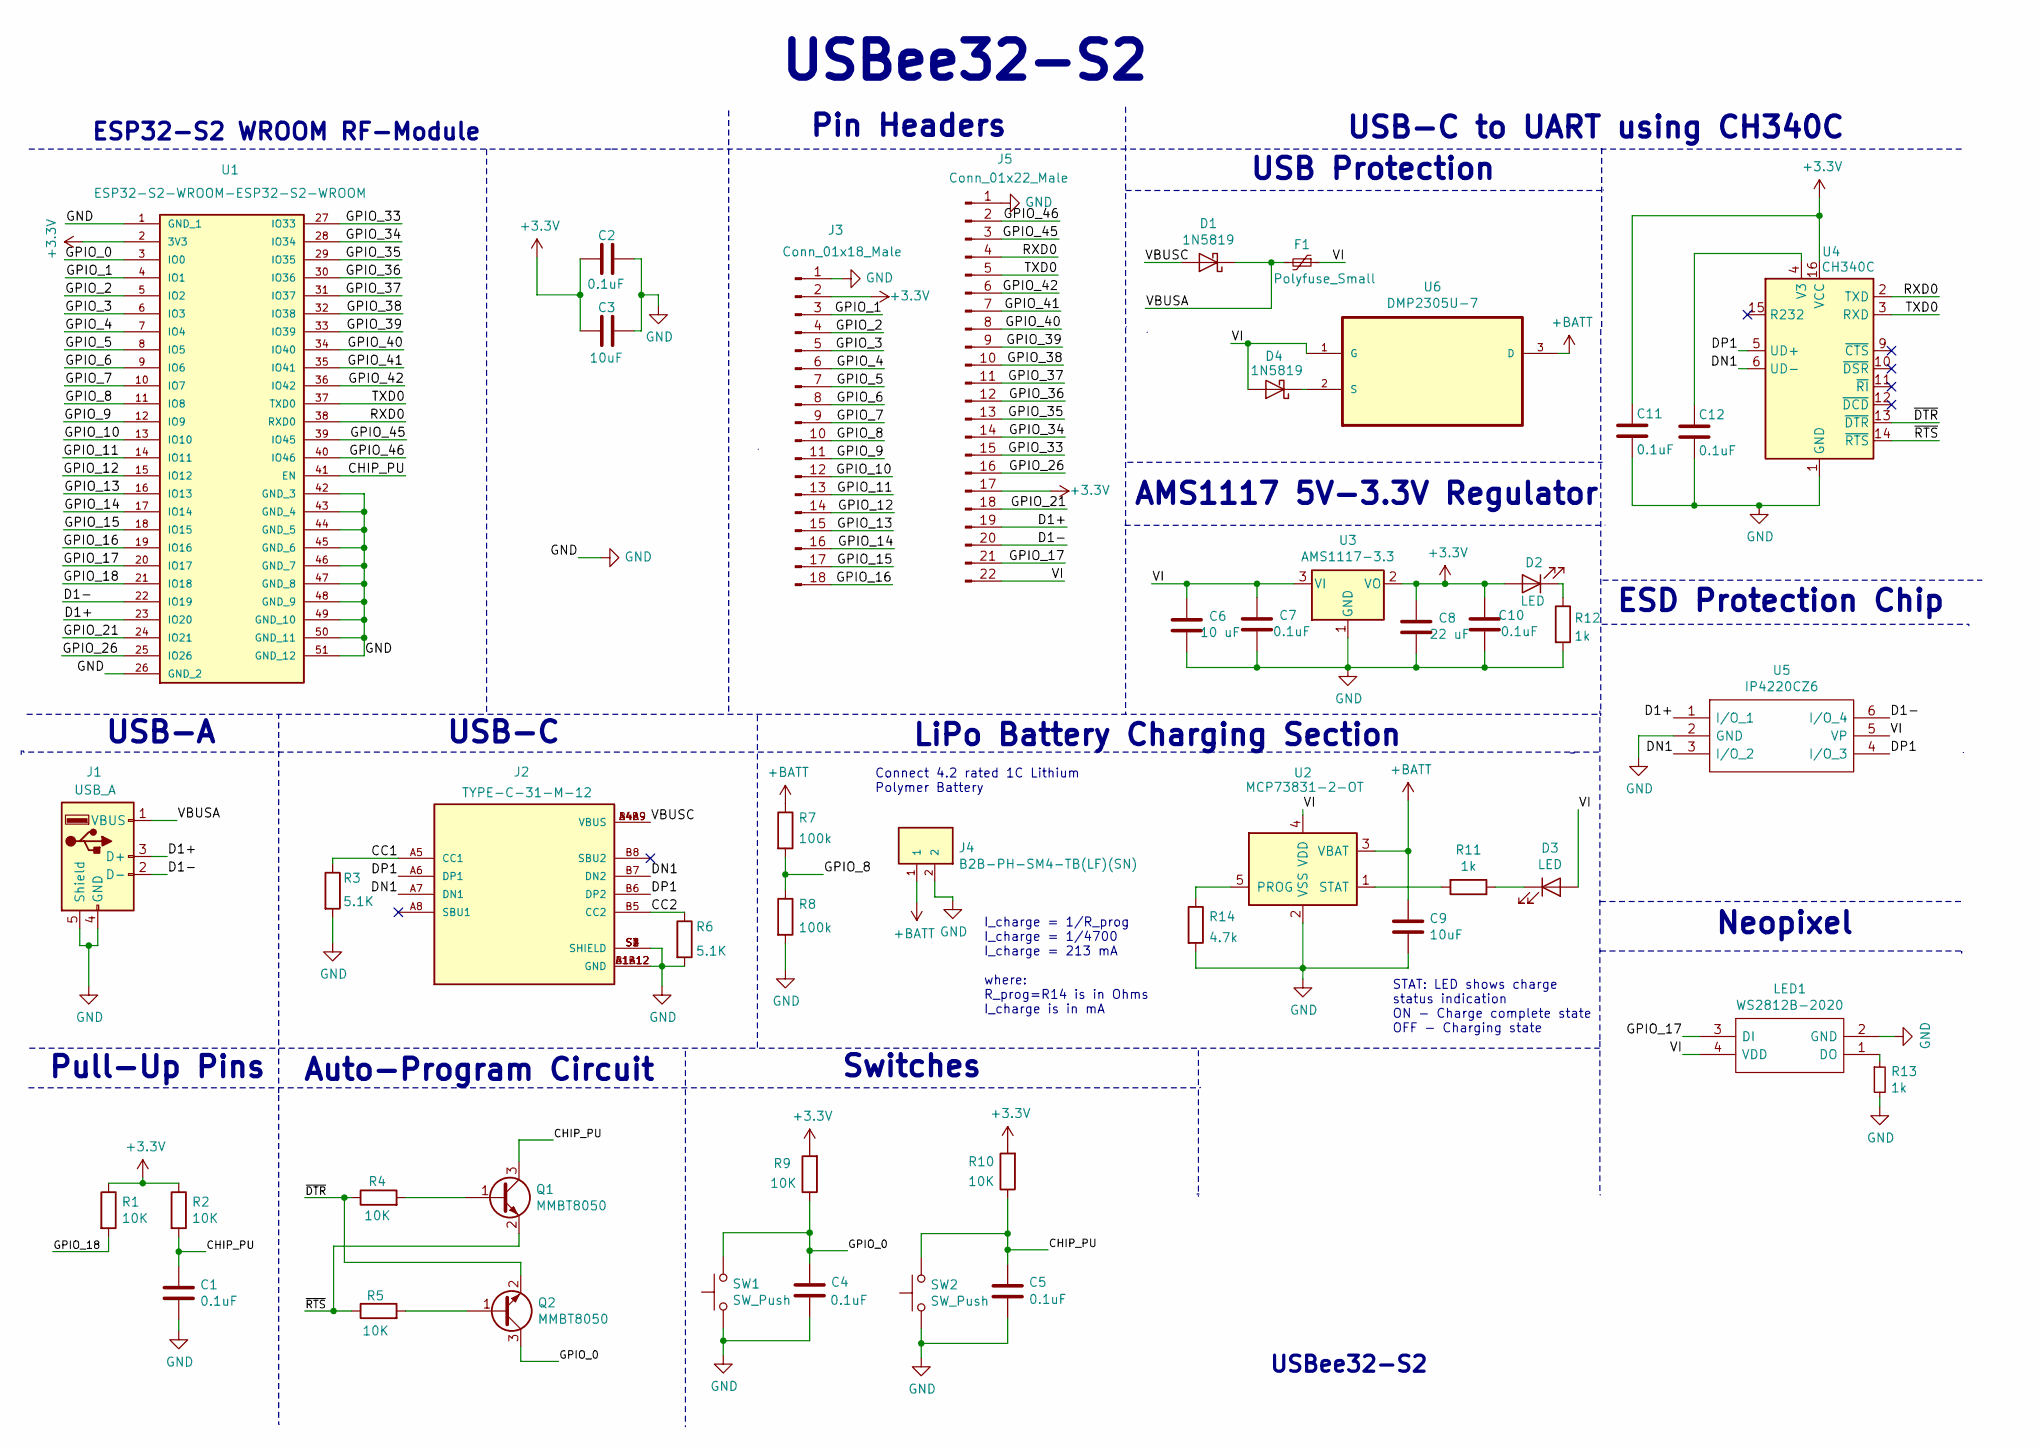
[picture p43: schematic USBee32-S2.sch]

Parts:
C1, C2, C4, C5, C7, C10, C11, C12: 0.1uF; C_0603_1608Metric
C3, C9: 10uF; C_0603_1608Metric
C6: 10 uF; C_0603_1608Metric
C8: 22 uF; C_0603_1608Metric
D1, D4: 1N5819; D_1206_3216Metric
D2, D3: LED; LED_0603_1608Metric_Castellated
F1: Polyfuse_Small; Fuse_1206_3216Metric
J1: USB_A; USB_A_Wuerth_614004134726_Horizontal
J2: TYPE-C-31-M-12; HRO_TYPE-C-31-M-12; PARTREV A
J3: Conn_01x18_Male; PinHeader_1x18_P2.54mm_Vertical
J4: B2B-PH-SM4-TB(LF)(SN); JST_B2B-PH-SM4-TB(LF)(SN)
J5: Conn_01x22_Male; PinHeader_1x22_P2.54mm_Vertical
LED1: WS2812B-2020; WS2812B2020; Manufacturer_Part_Number WS2812B-2020
Q1, Q2: MMBT8050
R1, R2, R4, R5, R9, R10: 10K; R_0603_1608Metric
R3, R6: 5.1K; R_0603_1608Metric
R7, R8: 100k; R_0603_1608Metric
R11, R12, R13: 1k; R_0603_1608Metric
R14: 4.7k; R_0603_1608Metric
SW1, SW2: SW_Push; tactile_smd_switch
U1: ESP32-S2-WROOM-ESP32-S2-WROOM; ESP32S2WROOMM22S2H3200PH3Q0; PARTREV V1.0
U2: MCP73831-2-OT; SOT-23-5
U3: AMS1117-3.3; SOT-223-3_TabPin2
U4: CH340C; SOIC-16_3.9x9.9mm_P1.27mm
U5: IP4220CZ6; SOP95P275X110-6N; Manufacturer_Part_Number IP4220CZ6; Mouser Part Number N/A
U6: DMP2305U-7; SOT103P240X110-3N; MPN DMP2305U-7

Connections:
+3V3: C2.1, C3.1, C8.2, C10.2, C11.1, D2.2 (A), J3.2, J5.17, R1.1, R2.1, R9.2, R10.2, U1.2 (3V3), U3.2 (VO), U4.16 (VCC)
+BATT: C9.1, J4.1, R7.1, U2.3 (VBAT), U6.3 (D)
/CC1: J2.A5 (CC1), R3.1
/CC2: J2.B5 (CC2), R6.1
/CHIP_PU: C1.1, C5.2, Q1.3, R2.2, R10.1, SW2.2, U1.41 (EN)
/D1+: J1.3 (D+), J5.19, U1.23 (IO20), U5.1 (I/O_1)
/D1-: J1.2 (D-), J5.20, U1.22 (IO19), U5.6 (I/O_4)
/DN1: J2.A7 (DN1), J2.B7 (DN2), U4.6 (UD-), U5.3 (I/O_2)
/DP1: J2.A6 (DP1), J2.B6 (DP2), U4.5 (UD+), U5.4 (I/O_3)
/GPIO_0: C4.2, Q2.3, R9.1, SW1.2, U1.3 (IO0)
/GPIO_1: J3.3, U1.4 (IO1)
/GPIO_2: J3.4, U1.5 (IO2)
/GPIO_3: J3.5, U1.6 (IO3)
/GPIO_4: J3.6, U1.7 (IO4)
/GPIO_5: J3.7, U1.8 (IO5)
/GPIO_6: J3.8, U1.9 (IO6)
/GPIO_7: J3.9, U1.10 (IO7)
/GPIO_8: J3.10, R7.2, R8.1, U1.11 (IO8)
/GPIO_9: J3.11, U1.12 (IO9)
/GPIO_10: J3.12, U1.13 (IO10)
/GPIO_11: J3.13, U1.14 (IO11)
/GPIO_12: J3.14, U1.15 (IO12)
/GPIO_13: J3.15, U1.16 (IO13)
/GPIO_14: J3.16, U1.17 (IO14)
/GPIO_15: J3.17, U1.18 (IO15)
/GPIO_16: J3.18, U1.19 (IO16)
/GPIO_17: J5.21, LED1.3 (DI), U1.20 (IO17)
/GPIO_18: R1.2, U1.21 (IO18)
/GPIO_21: J5.18, U1.24 (IO21)
/GPIO_26: J5.16, U1.25 (IO26)
/GPIO_33: J5.15, U1.27 (IO33)
/GPIO_34: J5.14, U1.28 (IO34)
/GPIO_35: J5.13, U1.29 (IO35)
/GPIO_36: J5.12, U1.30 (IO36)
/GPIO_37: J5.11, U1.31 (IO37)
/GPIO_38: J5.10, U1.32 (IO38)
/GPIO_39: J5.9, U1.33 (IO39)
/GPIO_40: J5.8, U1.34 (IO40)
/GPIO_41: J5.7, U1.35 (IO41)
/GPIO_42: J5.6, U1.36 (IO42)
/GPIO_45: J5.3, U1.39 (IO45)
/GPIO_46: J5.2, U1.40 (IO46)
/RXD0: J5.4, U1.38 (RXD0), U4.2 (TXD)
/TXD0: J5.5, U1.37 (TXD0), U4.3 (RXD)
/VBUSA: D1.1 (K), F1.2, J1.1 (VBUS)
/VBUSC: D1.2 (A), J2.A4B9 (VBUS), J2.B4A9 (VBUS)
/VI: C6.2, C7.2, D3.2 (A), D4.2 (A), F1.1, J5.22, LED1.4 (VDD), U2.4 (VDD), U3.3 (VI), U5.5 (VP), U6.1 (G)
/~DTR: Q2.2, R4.1, U4.13 (~DTR)
/~RTS: Q1.2, R5.1, U4.14 (~RTS)
GND: C1.2, C2.2, C3.2, C4.1, C5.1, C6.1, C7.1, C8.1, C9.2, C10.1, C11.2, C12.2, J1.4 (GND), J1.5 (Shield), J2.A1B12 (GND), J2.B1A12 (GND), J2.S1 (SHIELD), J2.S2 (SHIELD), J2.S3 (SHIELD), J2.S4 (SHIELD), J3.1, J4.2, J5.1, LED1.2 (GND), R3.2, R6.2, R8.2, R12.2, R13.2, R14.2, SW1.1, SW2.1, U1.1 (GND_1), U1.26 (GND_2), U1.42 (GND_3), U1.43 (GND_4), U1.44 (GND_5), U1.45 (GND_6), U1.46 (GND_7), U1.47 (GND_8), U1.48 (GND_9), U1.49 (GND_10), U1.50 (GND_11), U1.51 (GND_12), U2.2 (VSS), U3.1 (GND), U4.1 (GND), U5.2 (GND)
unnamed: C12.1, U4.4 (V3)
unnamed: D2.1 (K), R12.1
unnamed: D3.1 (K), R11.1
unnamed: D4.1 (K), U6.2 (S)
unnamed: LED1.1 (DO), R13.1
unnamed: Q1.1, R4.2
unnamed: Q2.1, R5.2
unnamed: R11.2, U2.1 (STAT)
unnamed: R14.1, U2.5 (PROG)

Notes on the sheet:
USB-C to UART using CH340C
USB-A
ESP32-S2 WROOM RF-Module
Pin Headers
USB-C
AMS1117 5V-3.3V Regulator
USB Protection
LiPo Battery Charging Section
ESD Protection Chip
Neopixel
I_charge = 1/R_prog I_charge = 1/4700 I_charge = 213 mA where: R_prog=R14 is in Ohms I_charge is in mA
Connect 4.2 rated 1C Lithium Polymer Battery
STAT: LED shows charge status indication ON - Charge complete state OFF - Charging state
USBee32-S2
Switches
Pull-Up Pins
Auto-Program Circuit

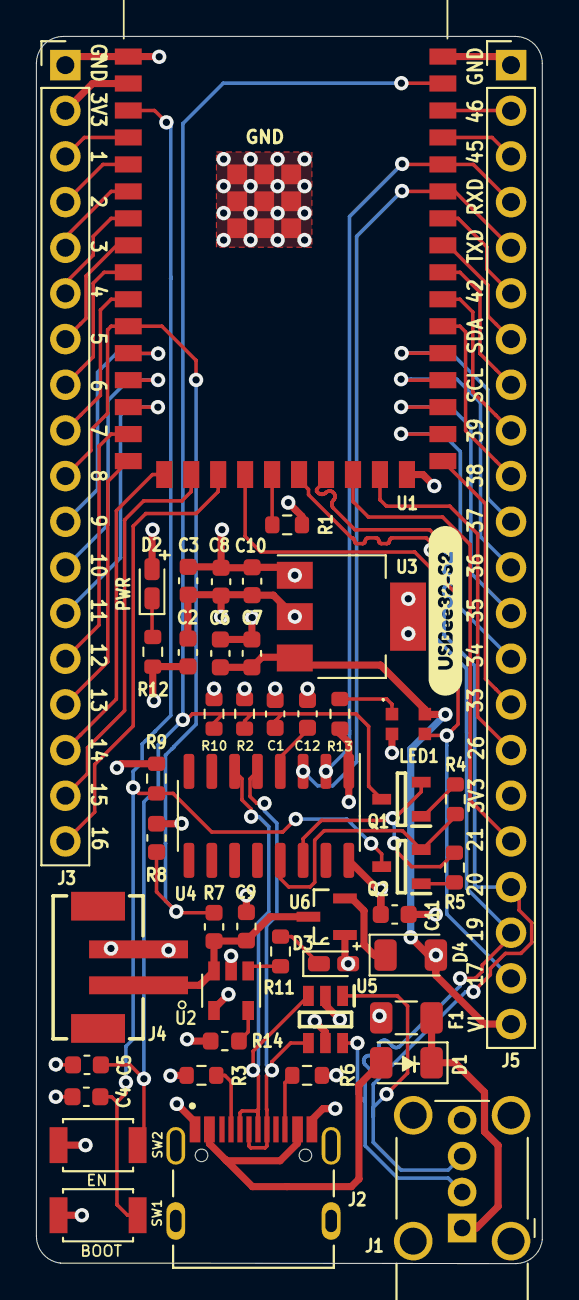
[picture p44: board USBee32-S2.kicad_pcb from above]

Board: 4 copper layers, 28.1 x 68.3 mm, 49 parts (1 on the bottom side), 59 nets.

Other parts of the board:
svg2mod, svg2mod#2: G***; label

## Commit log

2021-01-15 added rf, switches, basic schematic
    [ESP32-S2.kicad_pcb, ESP32-S2.sch]
2021-01-16 Added SSD1306 and Connectors
    [ESP32-S2.sch]
2021-01-16 added minor changes
    [ESP32-S2.sch]
2021-01-17 Added USB to UART
    [ESP32-S2.kicad_pcb, ESP32-S2.sch]
2021-01-18 resolved errors
    [ESP32-S2.sch]
2021-01-19 Some Changes in Schematic
    [ESP32-S2.kicad_pcb, ESP32-S2.sch]
2021-01-26 made suggested changes
    [ESP32-S2.sch]
2021-02-01 Made changes in schematics
    [ESP32-S2.sch]
2021-02-03 minor changes
    [ESP32-S2.sch]
2021-02-09 Changes in Schematic
    [ESP32-S2.kicad_pcb, ESP32-S2.sch]
2021-02-10 added footprints
    [ESP32-S2.sch]
2021-02-10 Started Routing
    [ESP32-S2.kicad_pcb, ESP32-S2.sch]
2021-02-11 Updated schematic with proper footprints
    [ESP32-S2.kicad_pcb, ESP32-S2.sch, TYPE-C-31-M-12.step]
2021-02-13 basic routing and placement
    [ESP32-S2.kicad_pcb, ESP32-S2.sch, L8050QLT1G.stl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]
2021-02-14 updated schematics
    [ESP32-S2.kicad_pcb, ESP32-S2.sch]
2021-02-15 layout, schematic finalised
    [ESP32-S2.kicad_pcb, ESP32-S2.sch]
2021-03-17 Test Routing Done
    [ESP32-S2.sch]
2021-03-17 Routing Updates
    [ESP32-S2.kicad_pcb]
2021-03-17 Cleaned up routing
    [ESP32-S2.kicad_pcb]
2021-03-17 Updated Routing
    [ESP32-S2.kicad_pcb]
2021-03-17 optimised routing further
    [ESP32-S2.kicad_pcb]
2021-03-17 Switches added
    [ESP32-S2.kicad_pcb, ESP32-S2.sch]
2021-03-17 added 3D models
    [ESP32-S2-WROOM_M22S2H3200PH3Q0_.stl, ESP32-S2-WROOM_M22S2H3200PH3Q0_.stp, ESP32-S2.kicad_pcb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]
2021-03-17 added 3D model:switch
    [ESP32-S2-WROVER.STEP, ESP32-S2.kicad_pcb]
2021-03-17 modified and fixed silkscreem
    [ESP32-S2.kicad_pcb]
2021-03-17 Silkscreen Modified
    [ESP32-S2.kicad_pcb]
2021-03-17 Changes in Routing and Silkscreen
    [ESP32-S2.kicad_pcb, ESP32-S2.sch]
2021-03-17 optimised routing
    [ESP32-S2.kicad_pcb]
2021-03-17 made changes- routing and schematic, added silk screen- pin headers
    [ESP32-S2.kicad_pcb, ESP32-S2.sch]
2021-03-17 Changes in PCB
    [ESP32-S2.kicad_pcb]
2021-03-17 Updated and optimised routing
    [ESP32-S2.kicad_pcb]
2021-03-17 added name, corrected annotations
    [ESP32-S2.kicad_pcb, ESP32-S2.sch]
2021-03-17 addedassets, updateed silkscreen
    [ESP32-S2.kicad_pcb, ESP32-S2.sch]
2021-03-18 Added 3d model for Polyfuse
    [BAT760-7.stl, BAT760-7.stp, ESP32-S2.kicad_pcb]
2021-03-18 changed Polyfuse package 0603->1206
    [ESP32-S2.kicad_pcb, ESP32-S2.sch]
2021-03-19 updated renders, screenshots
    [ESP32-S2.kicad_pcb]
2021-03-20 Finalised kicad design
    [ESP32-S2.kicad_pcb, ESP32-S2.sch]
2021-03-20 Added gerbers
    [ESP32-S2-B_Cu.gbr, ESP32-S2-B_Mask.gbr, ESP32-S2-B_Paste.gbr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]
2021-03-20 Updated routing to remove vias in pads
    [ESP32-S2-B_Cu.gbr, ESP32-S2-B_Mask.gbr, ESP32-S2-B_Paste.gbr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]
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2021-03-21 Addded renders
    [ESP32-S2-B_SilkS.dxf, ESP32-S2-F_SilkS.dxf, esp32-s2-dev-board.FCStd]
2021-03-22 added updated renders, datasheets
    [ESP32-S2.kicad_pcb]
2021-03-22 Set grid origin and fixed few issues with pcb
    [ESP32-S2.kicad_pcb]
2021-03-22 Added 3d renders
    [esp32-s2-dev-board.FCStd]
2021-03-24 Add kitspace.yaml and 1-click-bom.csv
    [1-click-bom.csv]
2021-03-26 Added Battery Charging and Neopixel
    [BU2032SM-BT-GTR.step, DMP2305U-7.step, ESP32-S2.kicad_pcb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]
2021-05-12 changed bat760 with 1n5819
    [ESP32-S2.kicad_pcb, ESP32-S2.sch]
2021-05-12 Added IP4220CZ6 - ESD Protection Device
    [ESP32-S2.sch]
2021-05-12 added IP4220CZ6 connections, symbol, footprint
    [ESP32-S2.kicad_pcb, ESP32-S2.sch]
2021-05-14 Updated 4lyr schematics, datasheets
    [ESP32-S2.sch, S2B-PH-SM4-TB_LF__SN_.step]
2021-05-14 Changed Neopixel
    [ESP32-S2.sch]
2021-05-15 replaces L8050QLT1G with MMBT8050
    [ESP32-S2.kicad_pcb, ESP32-S2.sch]
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2021-05-27 Optimised layer distribution and routing in PWR plane
    [ESP32-S2.kicad_pcb]
2021-05-27 Fixed undetected board boundaries
    [ESP32-S2.kicad_pcb]
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2021-05-30 added minor routing changes
    [ESP32-S2.kicad_pcb]
2021-06-02 Optimised 4-lyr routing v.4lyr.2
    [ESP32-S2.kicad_pcb, ESP32-S2.sch]
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2021-06-06 Optimised 4-lyr routing v.4lyr.3
    [ESP32-S2.kicad_pcb, ESP32-S2.sch]
2021-06-07 minor changes to v.4lyr.3
    [ESP32-S2.kicad_pcb]
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2021-06-08 Modified silkscreen and final changes
    [BC847,215.stl, BC847,215.stp, ESP32-S2.kicad_pcb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]
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2021-06-10 Correcteed qr, rounded corners, added files
    [BAT760-7.stl, BAT760-7.stp, BC847,215.stl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]
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2021-06-11 Fixed GPIO Number on silkscreen
    [USBee32-S2.kicad_pcb]
2021-06-11 Cleaned up renders, gerbers
    [ESP32-S2-NPTH-drl_map.gbr, ESP32-S2-NPTH.drl, ESP32-S2-PTH-drl_map.gbr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]
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2021-06-18 Made suggested changes in schematics
    [USBee32-S2.kicad_pcb]
2021-06-25 Rotated UsbC and added differential pair
    [USBee32-S2.kicad_pcb]
2021-06-27 Made minor changes in routing
    [USBee32-S2.kicad_pcb]
2021-06-28 Added missing silkscreen and fixed edgecuts
    [USBee32-S2.kicad_pcb]
2021-07-12 Made suggested routing, placement changes
    [JST-PH_Vertical.step, USBee32-S2.kicad_pcb, USBee32-S2.sch]
2021-07-14 Updated routing, fixed issue with usb differential pair
    [USBee32-S2.kicad_pcb]
2021-07-14 Completed routing 4-layer board
    [B2B-PH-SM4-TB_LF__SN_.step, JST-PH_Vertical.step, S2B-PH-SM4-TB_LF__SN_.step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]
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2021-07-15 Routing and placement cleaned
    [USBee32-S2.kicad_pcb, USBee32-S2.sch]
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2021-07-15 Added differential pair to USB circuitry
    [USBee32-S2.kicad_pcb, USBee32-S2.sch]
2021-07-17 Updated renders, gerbers and assets (#18)
    [USBee32-S2-B_Cu.gbr, USBee32-S2-B_Mask.gbr, USBee32-S2-B_Paste.gbr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]
2021-09-30 Rectified neopixel, battery charging errors, updated routing
    [BAT760-7.stl, BAT760-7.stp, MMBT8050.stl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]
2021-09-30 Added pMOS DMP230U-7 for power mode select
    [USBee32-S2.kicad_pcb]
2021-10-10 Fixed Battery Charging Circuit
    [USBee32-S2.kicad_pcb, USBee32-S2.sch]
2021-10-10 Updated gerbers, renders and assets for v.3
    [USBee32-S2-B_Cu.gbr, USBee32-S2-B_Mask.gbr, USBee32-S2-B_Paste.gbr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]
